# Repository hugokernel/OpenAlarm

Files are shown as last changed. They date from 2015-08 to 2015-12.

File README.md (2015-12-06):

OpenAlarm
=========

Un système d'alarme libre.

Caractéristiques :

- Uniquement basé sur des briques libres (OpenSource / OpenHardware)
- Autonomie très grande des modules capteurs, appelés « Node » (plusieurs mois)
- Les Node sont basés sur un µcontrolleur Atmel AVR ATMega32U4 et l'interface radio, sur un RFM12B (basé sur un Si4421 http://www.silabs.com/products/wireless/EZRadio/Pages/Si442021.aspx)
- Programmation et recharge simple des Node par USB (port µUSB inclu)
- Pas besoin de base : 2 Node suffisent à faire fonctionner une surveillance
- Possibilité de modifier les paramètres d'un Node à distance
- Technos utilisées : Arduino (Ino) pour les Node, et Python pour l'interface avec un PC
- Les entrées / sorties sont facilement accessible (au pas de 2.54mm)
- 2 leds (vertes et rouges) inclues sur chaque Node

Les premiers Node sont fonctionnel en version 1.5.0, les schémas de principe et PCB sont disponible en PDF dans le dossier https://github.com/hugokernel/OpenAlarm/blob/master/hardware/export/pdf/node/1.5.0/

Pour rester informer, ça se passe sur le site officiel d'OpenAlarm http://openalarm.net/, vous pouvez venir en parler sur le canal irc #madeinfr sur le réseau freenode.

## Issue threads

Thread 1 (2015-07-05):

Schémas et typons PDF

nicolasc-eu, 2015-07-05:
Hello,

Petite suggestion : un export PDF et/ou bitmap des schémas et typons serait bien appréciable, pour pouvoir notamment les consulter sur mobile.

À plus tard,

hugokernel, 2015-12-05:
Done ! https://github.com/hugokernel/OpenAlarm/tree/master/hardware/export/pdf/node/1.5.0

Closed 2015-12-05.

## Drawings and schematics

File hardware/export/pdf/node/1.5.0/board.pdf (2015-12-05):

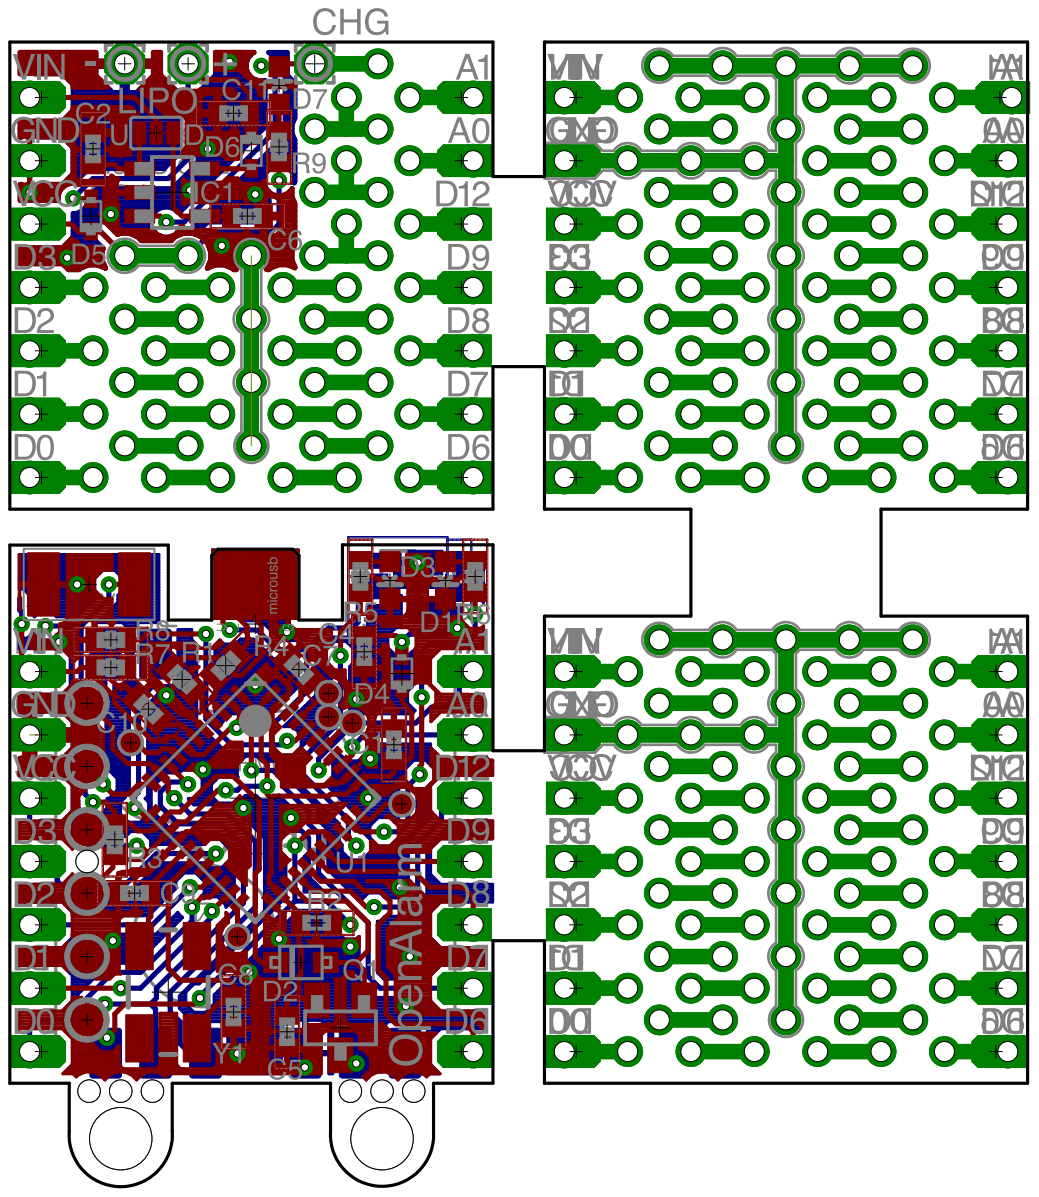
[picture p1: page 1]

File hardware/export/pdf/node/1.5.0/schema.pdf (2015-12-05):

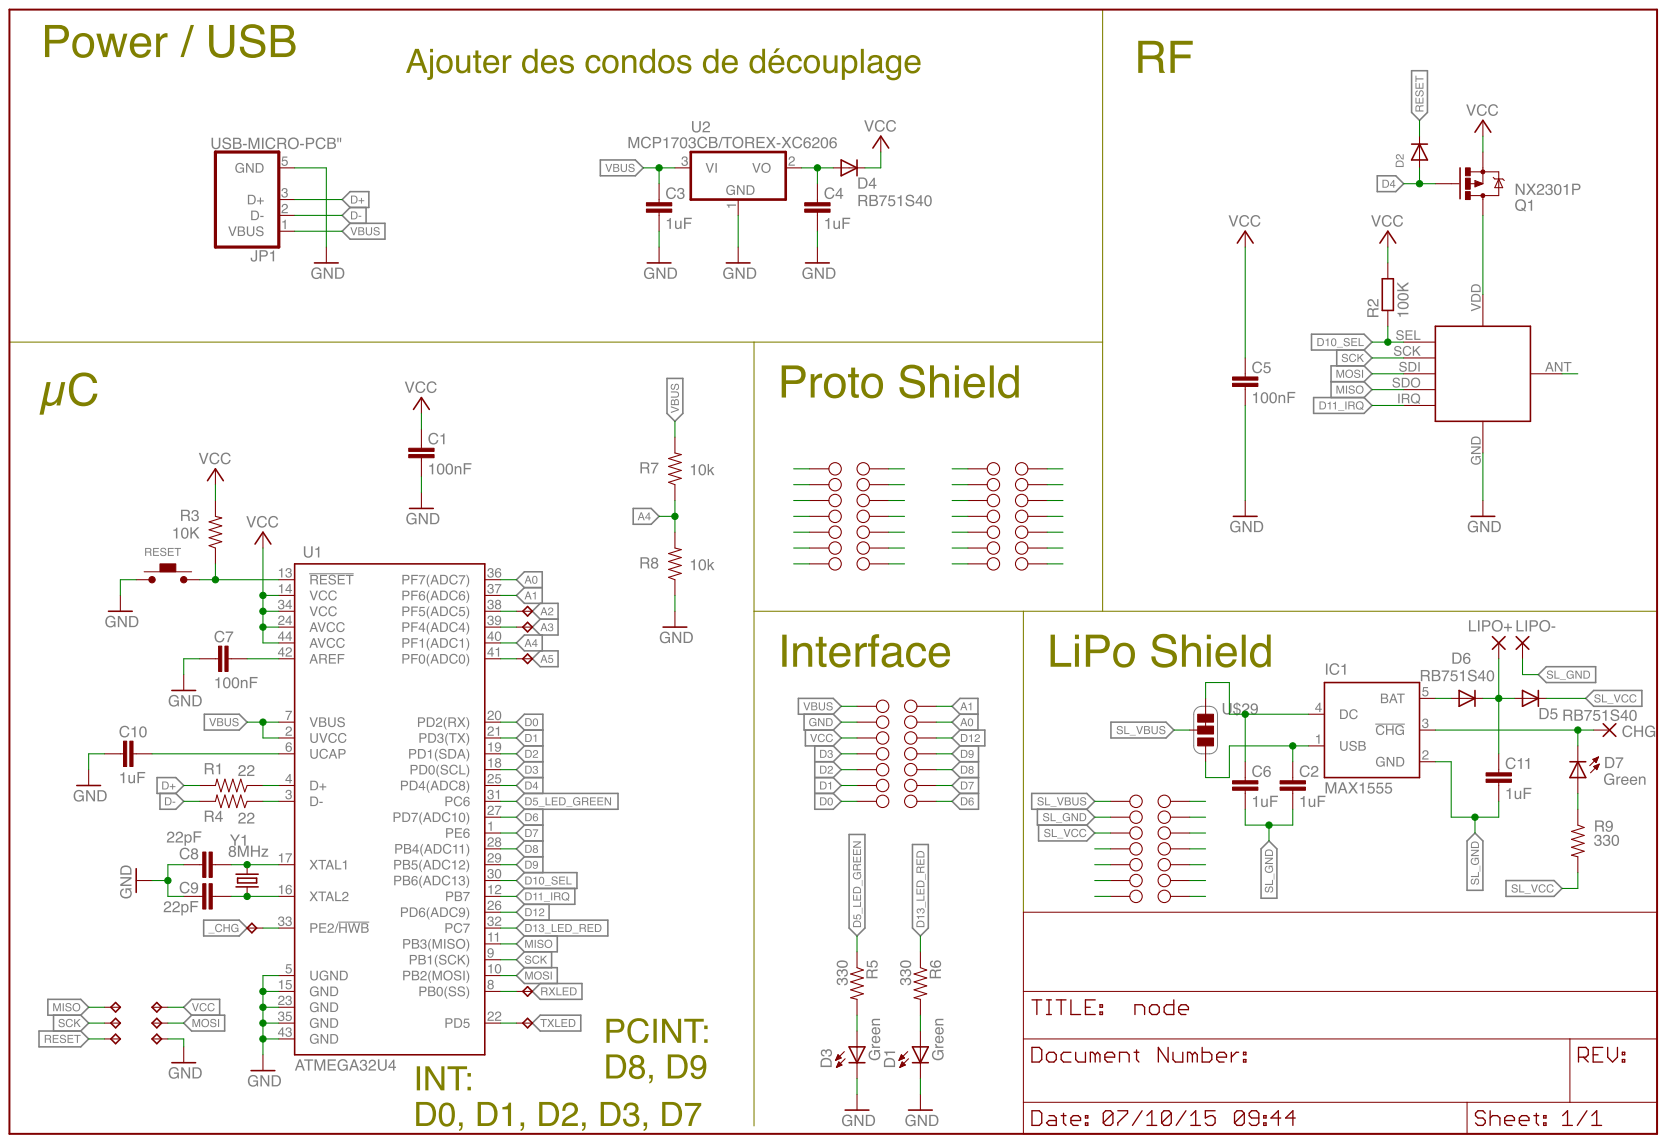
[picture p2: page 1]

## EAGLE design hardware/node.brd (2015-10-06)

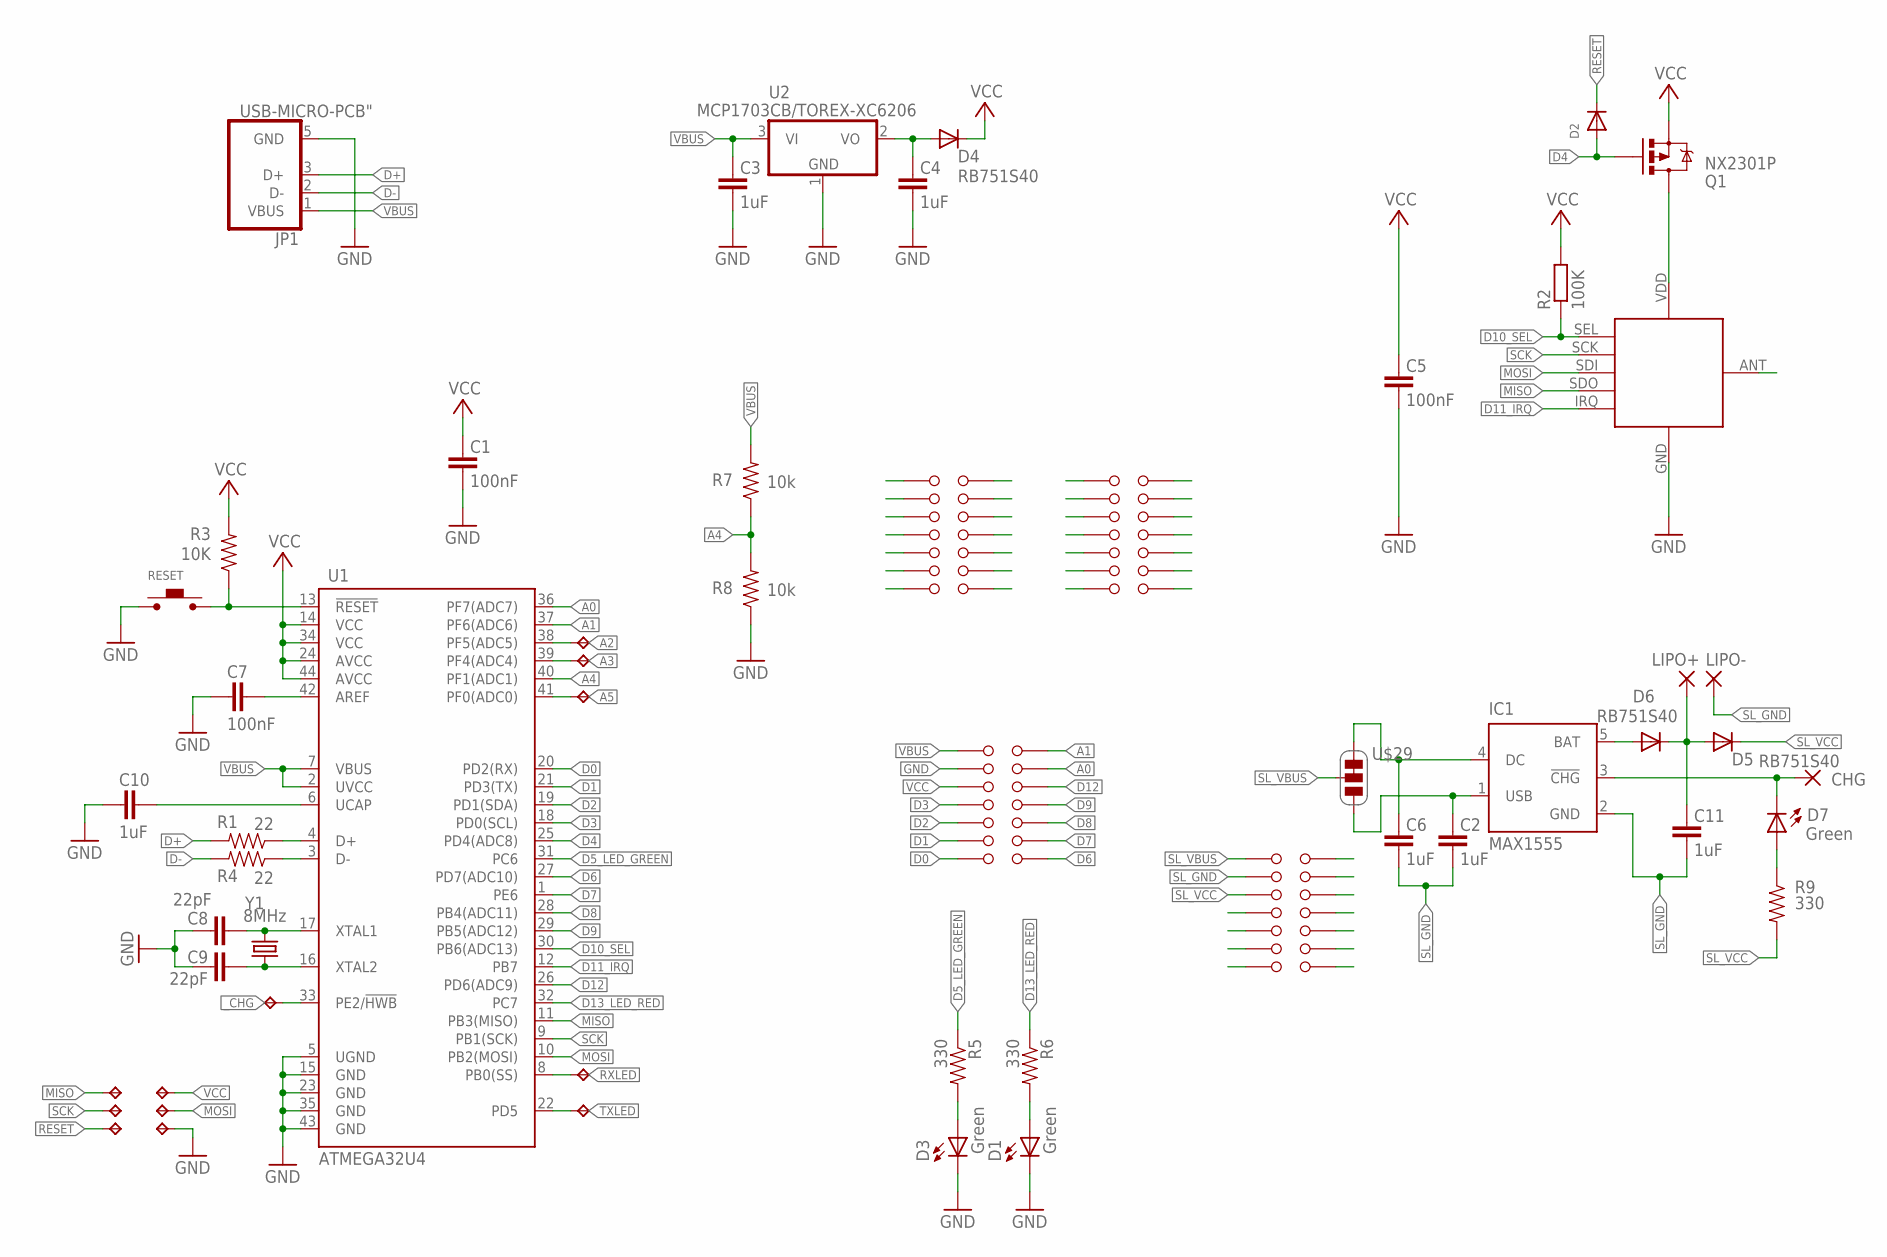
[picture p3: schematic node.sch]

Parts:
C1, C5, C7: 100nF; 0402-CAP
C2, C3, C4, C6, C10, C11: 1uF; 0402-CAP
C8, C9: 22pF; 0402-CAP
CHG: WIREPAD1,6/0,8; 1,6/0,8
D1, D3, D7: Green; LED-0603
D2: DIODESOD-323F; SOD-323F
D4, D5, D6: RB751S40; SOD523
IC1: MAX1555; SOT23-5L
JP1: USB-MICRO-PCB"; USB-MICRO-PCB
LIPO+: WIREPAD1,6/0,8; 1,6/0,8
LIPO-: WIREPAD1,6/0,8; 1,6/0,8
Q1: NX2301P; SOT23
R1, R4: 22; 0402-RES
R2: 100K; R0402
R3: 10K; 0402-RES
R5, R6, R9: 330; 0402-RES
R7, R8: 10k; 0402-RES
RESET: MICROSWITCH
RFMXX: RFM12B_MINPADS; RFM12B-MINPADS
TP1, TP2, TP3, TP4, TP5, TP14: TPTP13R; TP13R
TP7, TP8, TP9, TP10, TP11, TP12: TPTP08R; TP08R
U1: ATMEGA32U4; QFN-44-NOPAD
U2: MCP1703CB/TOREX-XC6206; SOT23
U$1, U$2, U$3, U$4, U$5, U$6, U$7, U$8, U$9, U$10, U$11, U$12, U$13, U$14, U$15, U$16, U$17, U$18, U$19, U$20, U$21, U$22, U$23, U$24, U$25, U$26, U$27, U$28, U$30, U$31, U$32, U$33, U$34, U$35, U$36, U$37, U$38, U$39, U$40, U$41, U$42, U$43, U$44, U$45, U$46, U$47, U$48, U$49, U$50, U$51, U$52, U$53, U$54, U$55, U$56, U$57: IOPAD
U$29: UJUMPER-SHORT
Y1: 8MHz; CRYSTAL-SMD-5X3

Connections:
A0: U1.36 (PF7(ADC7)), U$9.P$1
A1: U1.37 (PF6(ADC6)), U$8.P$1
A2: TP7.TP, U1.38 (PF5(ADC5))
A3: TP8.TP, U1.39 (PF4(ADC4))
A4: R7.1, R8.2, U1.40 (PF1(ADC1))
A5: TP10.TP, U1.41 (PF0(ADC0))
AREF: C7.2, U1.42 (AREF)
D0: U1.20 (PD2(RX)), U$2.P$1
D1: U1.21 (PD3(TX)), U$1.P$1
D2: U1.19 (PD1(SDA)), U$3.P$1
D3: U1.18 (PD0(SCL)), U$4.P$1
D4: D2.A, Q1.1 (G), U1.25 (PD4(ADC8))
D5_LED_GREEN: R5.1, U1.31 (PC6)
D6: U1.27 (PD7(ADC10)), U$14.P$1
D7: U1.1 (PE6), U$13.P$1
D8: U1.28 (PB4(ADC11)), U$12.P$1
D9: U1.29 (PB5(ADC12)), U$11.P$1
D10_SEL: R2.1, RFMXX.SEL, U1.30 (PB6(ADC13))
D11_IRQ: RFMXX.IRQ, U1.12 (PB7)
D12: U1.26 (PD6(ADC9)), U$10.P$1
D13_LED_RED: R6.1, U1.32 (PC7)
D+: JP1.3 (D+), R1.2
D-: JP1.2 (D-), R4.2
GND: C1.1, C3.1, C4.1, C5.1, C7.1, C8.2, C9.2, C10.1, D1.C, D3.C, JP1.5 (GND), R8.1, RESET.P$1, RFMXX.GND, TP5.TP, U1.5 (UGND), U1.15 (GND), U1.23 (GND), U1.35 (GND), U1.43 (GND), U2.1 (GND), U$6.P$1
MISO: RFMXX.SDO (SDO/MISO), TP14.TP, U1.11 (PB3(MISO))
MOSI: RFMXX.SDI (SDI/MOSI), TP4.TP, U1.10 (PB2(MOSI))
unnamed: C9.1, U1.16 (XTAL2), Y1.1
unnamed: R1.1, U1.4 (D+)
unnamed: C8.1, U1.17 (XTAL1), Y1.3 (2)
unnamed: C10.2, U1.6 (UCAP)
unnamed: D1.A, R6.2
unnamed: R4.1, U1.3 (D-)
unnamed: D3.A, R5.2
unnamed: Q1.3 (D), RFMXX.VDD
unnamed: D7.A, R9.1
unnamed: CHG.1, D7.C, IC1.3 (!CHG)
unnamed: C6.2, IC1.4 (DC), U$29.C0
unnamed: C2.2, IC1.1 (USB), U$29.C1
unnamed: D6.A, IC1.5 (BAT)
unnamed: C11.2, D5.A, D6.C, LIPO+.1
RESET: D2.C, R3.1, RESET.P$2, TP3.TP, U1.13 (!RESET)
RXLED: TP11.TP, U1.8 (PB0(SS))
SCK: RFMXX.SCK, TP2.TP, U1.9 (PB1(SCK))
SL_GND: C2.1, C6.1, C11.1, IC1.2 (GND), LIPO-.1, U$31.P$1
SL_VBUS: U$29.COM, U$30.P$1
SL_VCC: D5.C, R9.2, U$32.P$1
TXLED: TP9.TP, U1.22 (PD5)
VBAT: C4.2, D4.A, U2.2 (VO)
VBUS: C3.2, JP1.1 (VBUS), R7.2, U1.2 (UVCC), U1.7 (VBUS), U2.3 (VI), U$7.P$1
VCC: C1.2, C5.2, D4.C, Q1.2 (S), R2.2, R3.2, TP1.TP, U1.14 (VCC), U1.24 (AVCC), U1.34 (VCC), U1.44 (AVCC), U$5.P$1
_CHG: TP12.TP, U1.33 (PE2/!HWB)

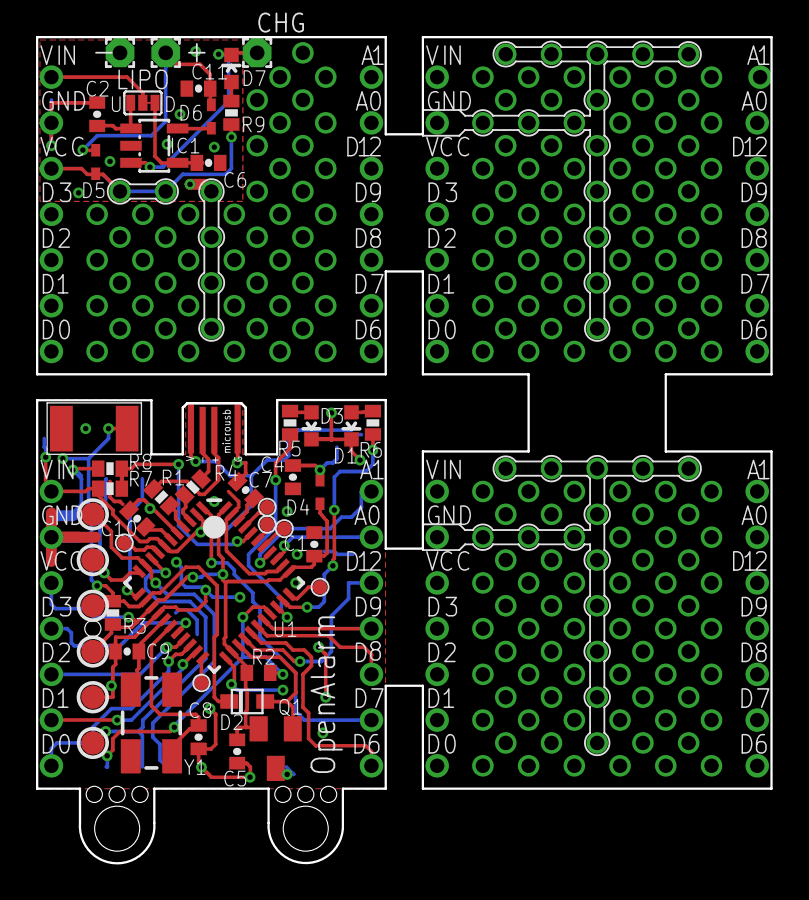
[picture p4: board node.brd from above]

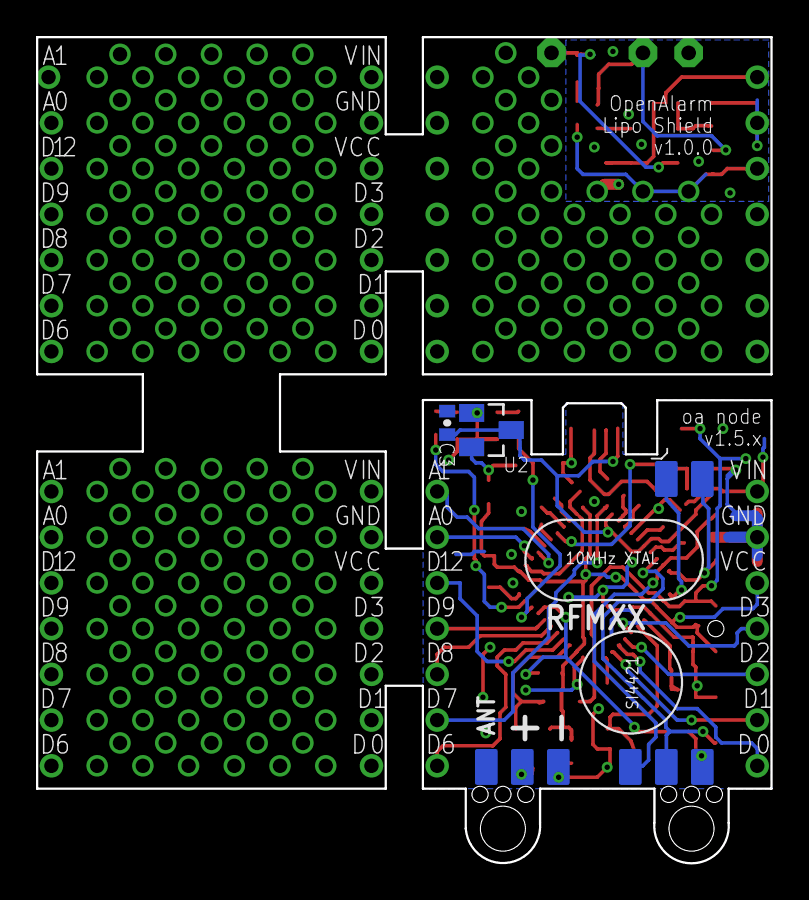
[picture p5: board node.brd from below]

Board: 2 copper layers, 40.8 x 45.9 mm, 107 parts (3 on the bottom side), 51 nets.

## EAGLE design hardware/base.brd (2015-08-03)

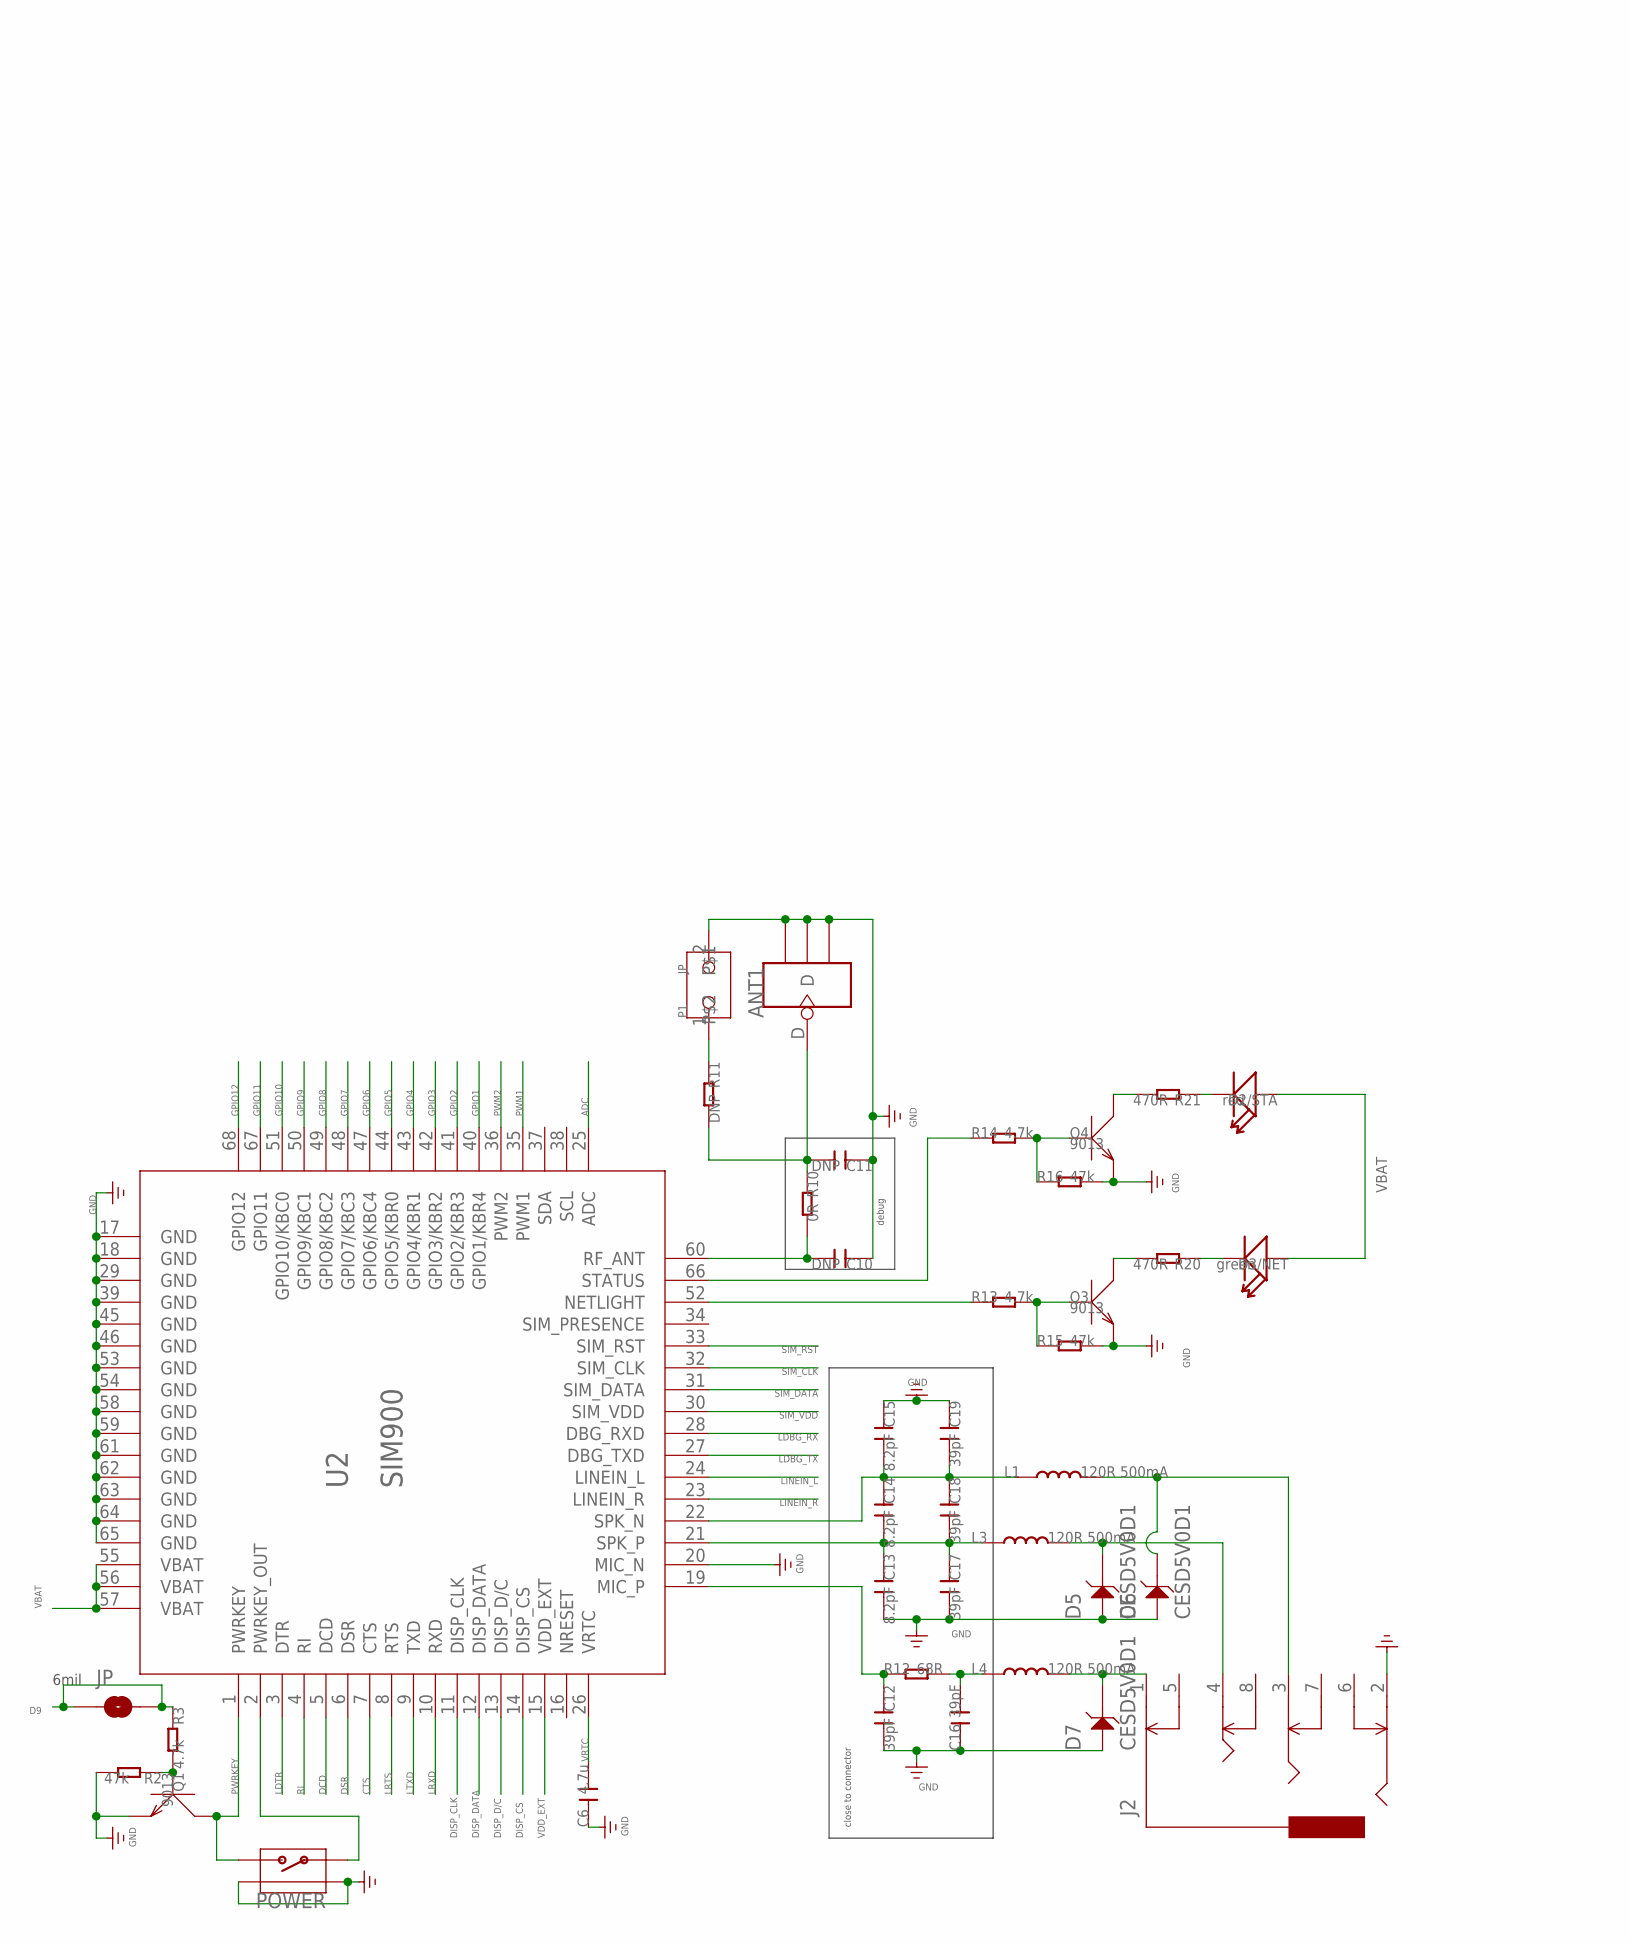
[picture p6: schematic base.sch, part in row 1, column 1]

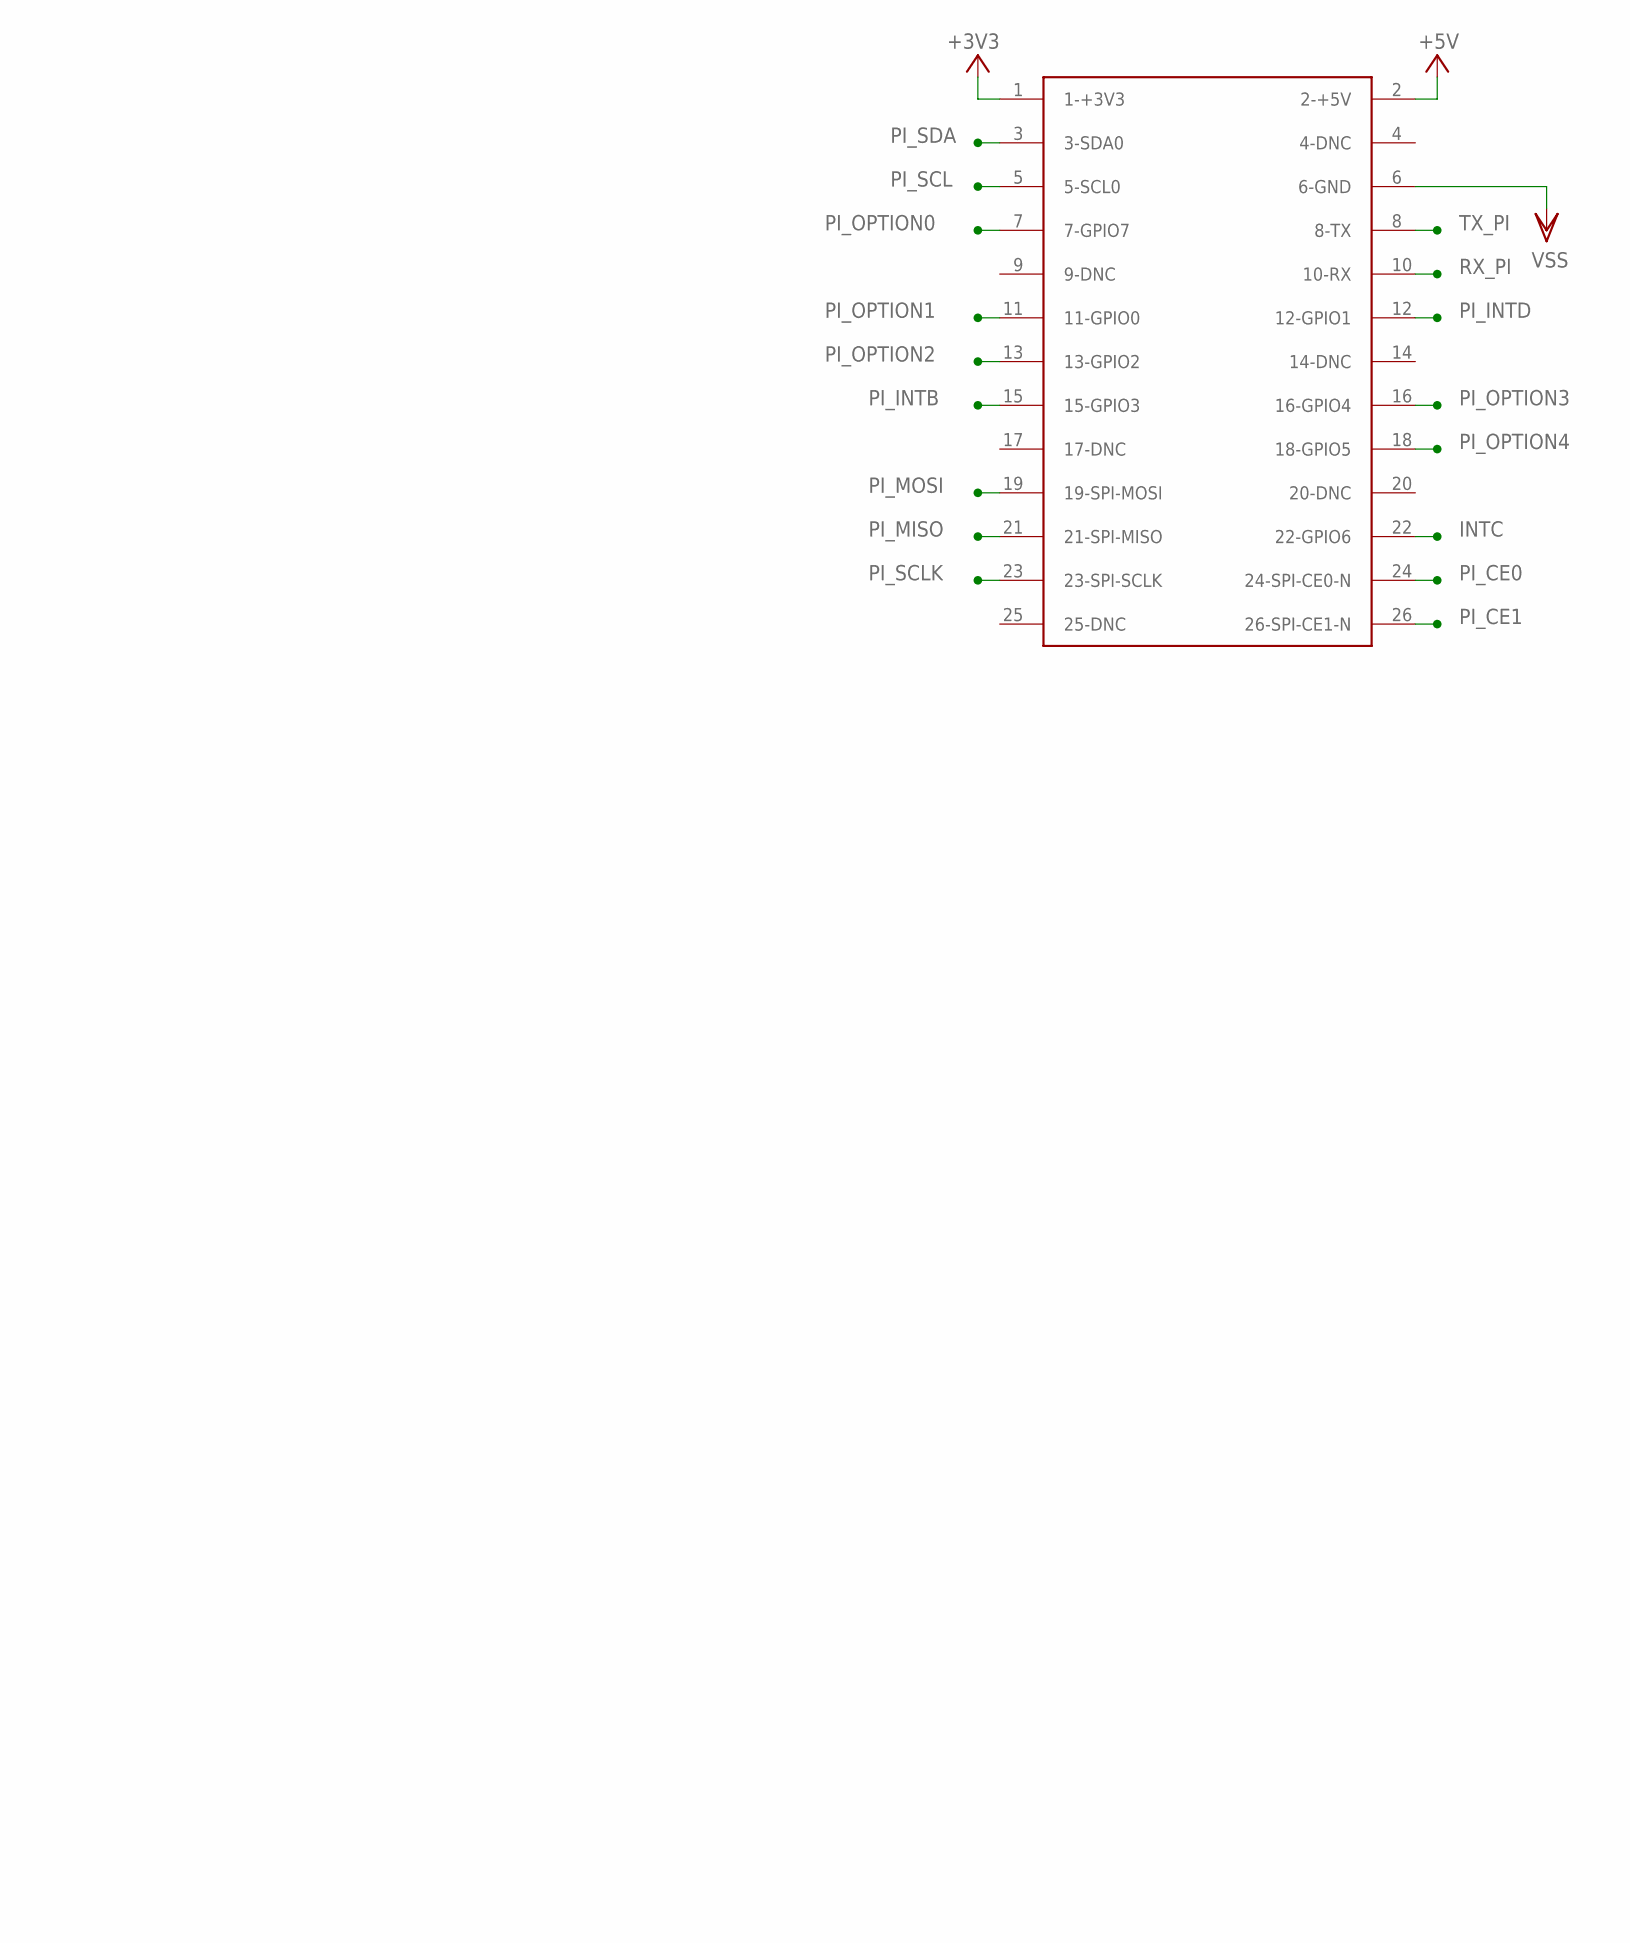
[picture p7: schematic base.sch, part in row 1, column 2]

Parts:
ANT1: ANTENNA-U-FL; 4P-U-FL
C6: 4.7u; C0805
C10, C11: DNP; C0603
C12, C16, C17, C18, C19: 39pF; C0603
C13, C14, C15: 8.2pF; C0603
D2/STA: red; LED-0603
D3/NET: green; LED-0603
D5, D6, D7: CESD5V0D1; SOD123-2.7X1.6
J2: AUDIO-8P'PJ-3536-L6S'; 8P-3.5-SMD
JP: PAD-SOLDERJUMPERNC; 2P-SMD-3.3X2
L1, L3, L4: 120R 500mA; L0603
P1: JP
POWER: BUTTON-4P-REINFORCE'TS-118E'; 4P-SMD-7X3.5X3.5H
Q1, Q3, Q4: 9013; SOT23
R2, R15, R16: 47k; R0603
R3, R13, R14: 4.7k; R0603
R10: 0R; R0603
R11: DNP; R0603
R12: 68R; R0603
R20, R21: 470R; R0603
U2: SIM900
U$3: RASPBERRY-PILIGHT-HOLE; RASPBERRY-PI-LIGHT-HOLE

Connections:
+3V3: U$3.1 (1-+3V3)
+5V: U$3.2 (2-+5V)
ADC: U2.25 (ADC)
CTS: U2.7 (CTS)
D9: JP.1, JP.2, R3.1
DCD: U2.5 (DCD)
DISP_CLK: U2.11 (DISP_CLK)
DISP_CS: U2.14 (DISP_CS)
DISP_D/C: U2.13 (DISP_D/C)
DISP_DATA: U2.12 (DISP_DATA)
DSR: U2.6 (DSR)
GND: ANT1.GND1, ANT1.GND2, ANT1.GND3, C6.1, C10.1, C11.1, C12.2, C13.2, C15.1, C16.1, C17.2, C19.1, D5.1, D6.1, D7.1, J2.2, P1.2, POWER.S1, POWER.S2, Q1.2 (E), Q3.2 (E), Q4.2 (E), R2.2, R15.2, R16.2, U2.17 (GND), U2.18 (GND), U2.20 (MIC_N), U2.29 (GND), U2.39 (GND), U2.45 (GND), U2.46 (GND), U2.53 (GND), U2.54 (GND), U2.58 (GND), U2.59 (GND), U2.61 (GND), U2.62 (GND), U2.63 (GND), U2.64 (GND), U2.65 (GND)
GPIO1: U2.40 (GPIO1/KBR4)
GPIO2: U2.41 (GPIO2/KBR3)
GPIO3: U2.42 (GPIO3/KBR2)
GPIO4: U2.43 (GPIO4/KBR1)
GPIO5: U2.44 (GPIO5/KBR0)
GPIO6: U2.47 (GPIO6/KBC4)
GPIO7: U2.48 (GPIO7/KBC3)
GPIO8: U2.49 (GPIO8/KBC2)
GPIO9: U2.50 (GPIO9/KBC1)
GPIO10: U2.51 (GPIO10/KBC0)
GPIO11: U2.67 (GPIO11)
GPIO12: U2.68 (GPIO12)
INTC: U$3.22 (22-GPIO6)
LDBG_RX: U2.28 (DBG_RXD)
LDBG_TX: U2.27 (DBG_TXD)
LDTR: U2.3 (DTR)
LINEIN_L: U2.24 (LINEIN_L)
LINEIN_R: U2.23 (LINEIN_R)
LRTS: U2.8 (RTS)
LRXD: U2.10 (RXD)
LTXD: U2.9 (TXD)
unnamed: D2/STA.-, R21.1
unnamed: C10.2, R10.2, U2.60 (RF_ANT)
unnamed: Q3.3 (C), R20.2
unnamed: D3/NET.-, R20.1
unnamed: Q3.1 (B), R13.2, R15.1
unnamed: R13.1, U2.52 (NETLIGHT)
unnamed: POWER.1, U2.2 (PWRKEY_OUT)
unnamed: C12.1, R12.1, U2.19 (MIC_P)
unnamed: C13.1, C14.2, C17.1, C18.2, L3.1, U2.21 (SPK_P)
unnamed: Q4.3 (C), R21.2
unnamed: Q4.1 (B), R14.2, R16.1
unnamed: C14.1, C15.2, C18.1, C19.2, L1.1, U2.22 (SPK_N)
unnamed: R14.1, U2.66 (STATUS)
unnamed: ANT1.D, C11.2, R10.1, R11.2
unnamed: C16.2, L4.1, R12.2
unnamed: Q1.1 (B), R2.1, R3.2
unnamed: D7.2, J2.1, L4.2
unnamed: D5.2, J2.4, L3.2
unnamed: D6.2, J2.3, L1.2
unnamed: P1.1, R11.1
PI_CE0: U$3.24 (24-SPI-CE0-N)
PI_CE1: U$3.26 (26-SPI-CE1-N)
PI_INTB: U$3.15 (15-GPIO3)
PI_INTD: U$3.12 (12-GPIO1)
PI_MISO: U$3.21 (21-SPI-MISO)
PI_MOSI: U$3.19 (19-SPI-MOSI)
PI_OPTION0: U$3.7 (7-GPIO7)
PI_OPTION1: U$3.11 (11-GPIO0)
PI_OPTION2: U$3.13 (13-GPIO2)
PI_OPTION3: U$3.16 (16-GPIO4)
PI_OPTION4: U$3.18 (18-GPIO5)
PI_SCL: U$3.5 (5-SCL0)
PI_SCLK: U$3.23 (23-SPI-SCLK)
PI_SDA: U$3.3 (3-SDA0)
PWM1: U2.35 (PWM1)
PWM2: U2.36 (PWM2)
PWRKEY: POWER.2, Q1.3 (C), U2.1 (PWRKEY)
RI: U2.4 (RI)
RX_PI: U$3.10 (10-RX)
SIM_CLK: U2.32 (SIM_CLK)
SIM_DATA: U2.31 (SIM_DATA)
SIM_RST: U2.33 (SIM_RST)
SIM_VDD: U2.30 (SIM_VDD)
TX_PI: U$3.8 (8-TX)
VBAT: D2/STA.+, D3/NET.+, U2.55 (VBAT), U2.56 (VBAT), U2.57 (VBAT)
VDD_EXT: U2.15 (VDD_EXT)
VRTC: C6.2, U2.26 (VRTC)
VSS: U$3.6 (6-GND)

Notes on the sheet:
close to connector
debug
6mil

Board: 2 copper layers, 42 parts (1 on the bottom side), 25 nets, no tracks yet.

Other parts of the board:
U$2: OSHW_8X350_NOTEXT
U$5: OSHW_6X150_NOTEXT

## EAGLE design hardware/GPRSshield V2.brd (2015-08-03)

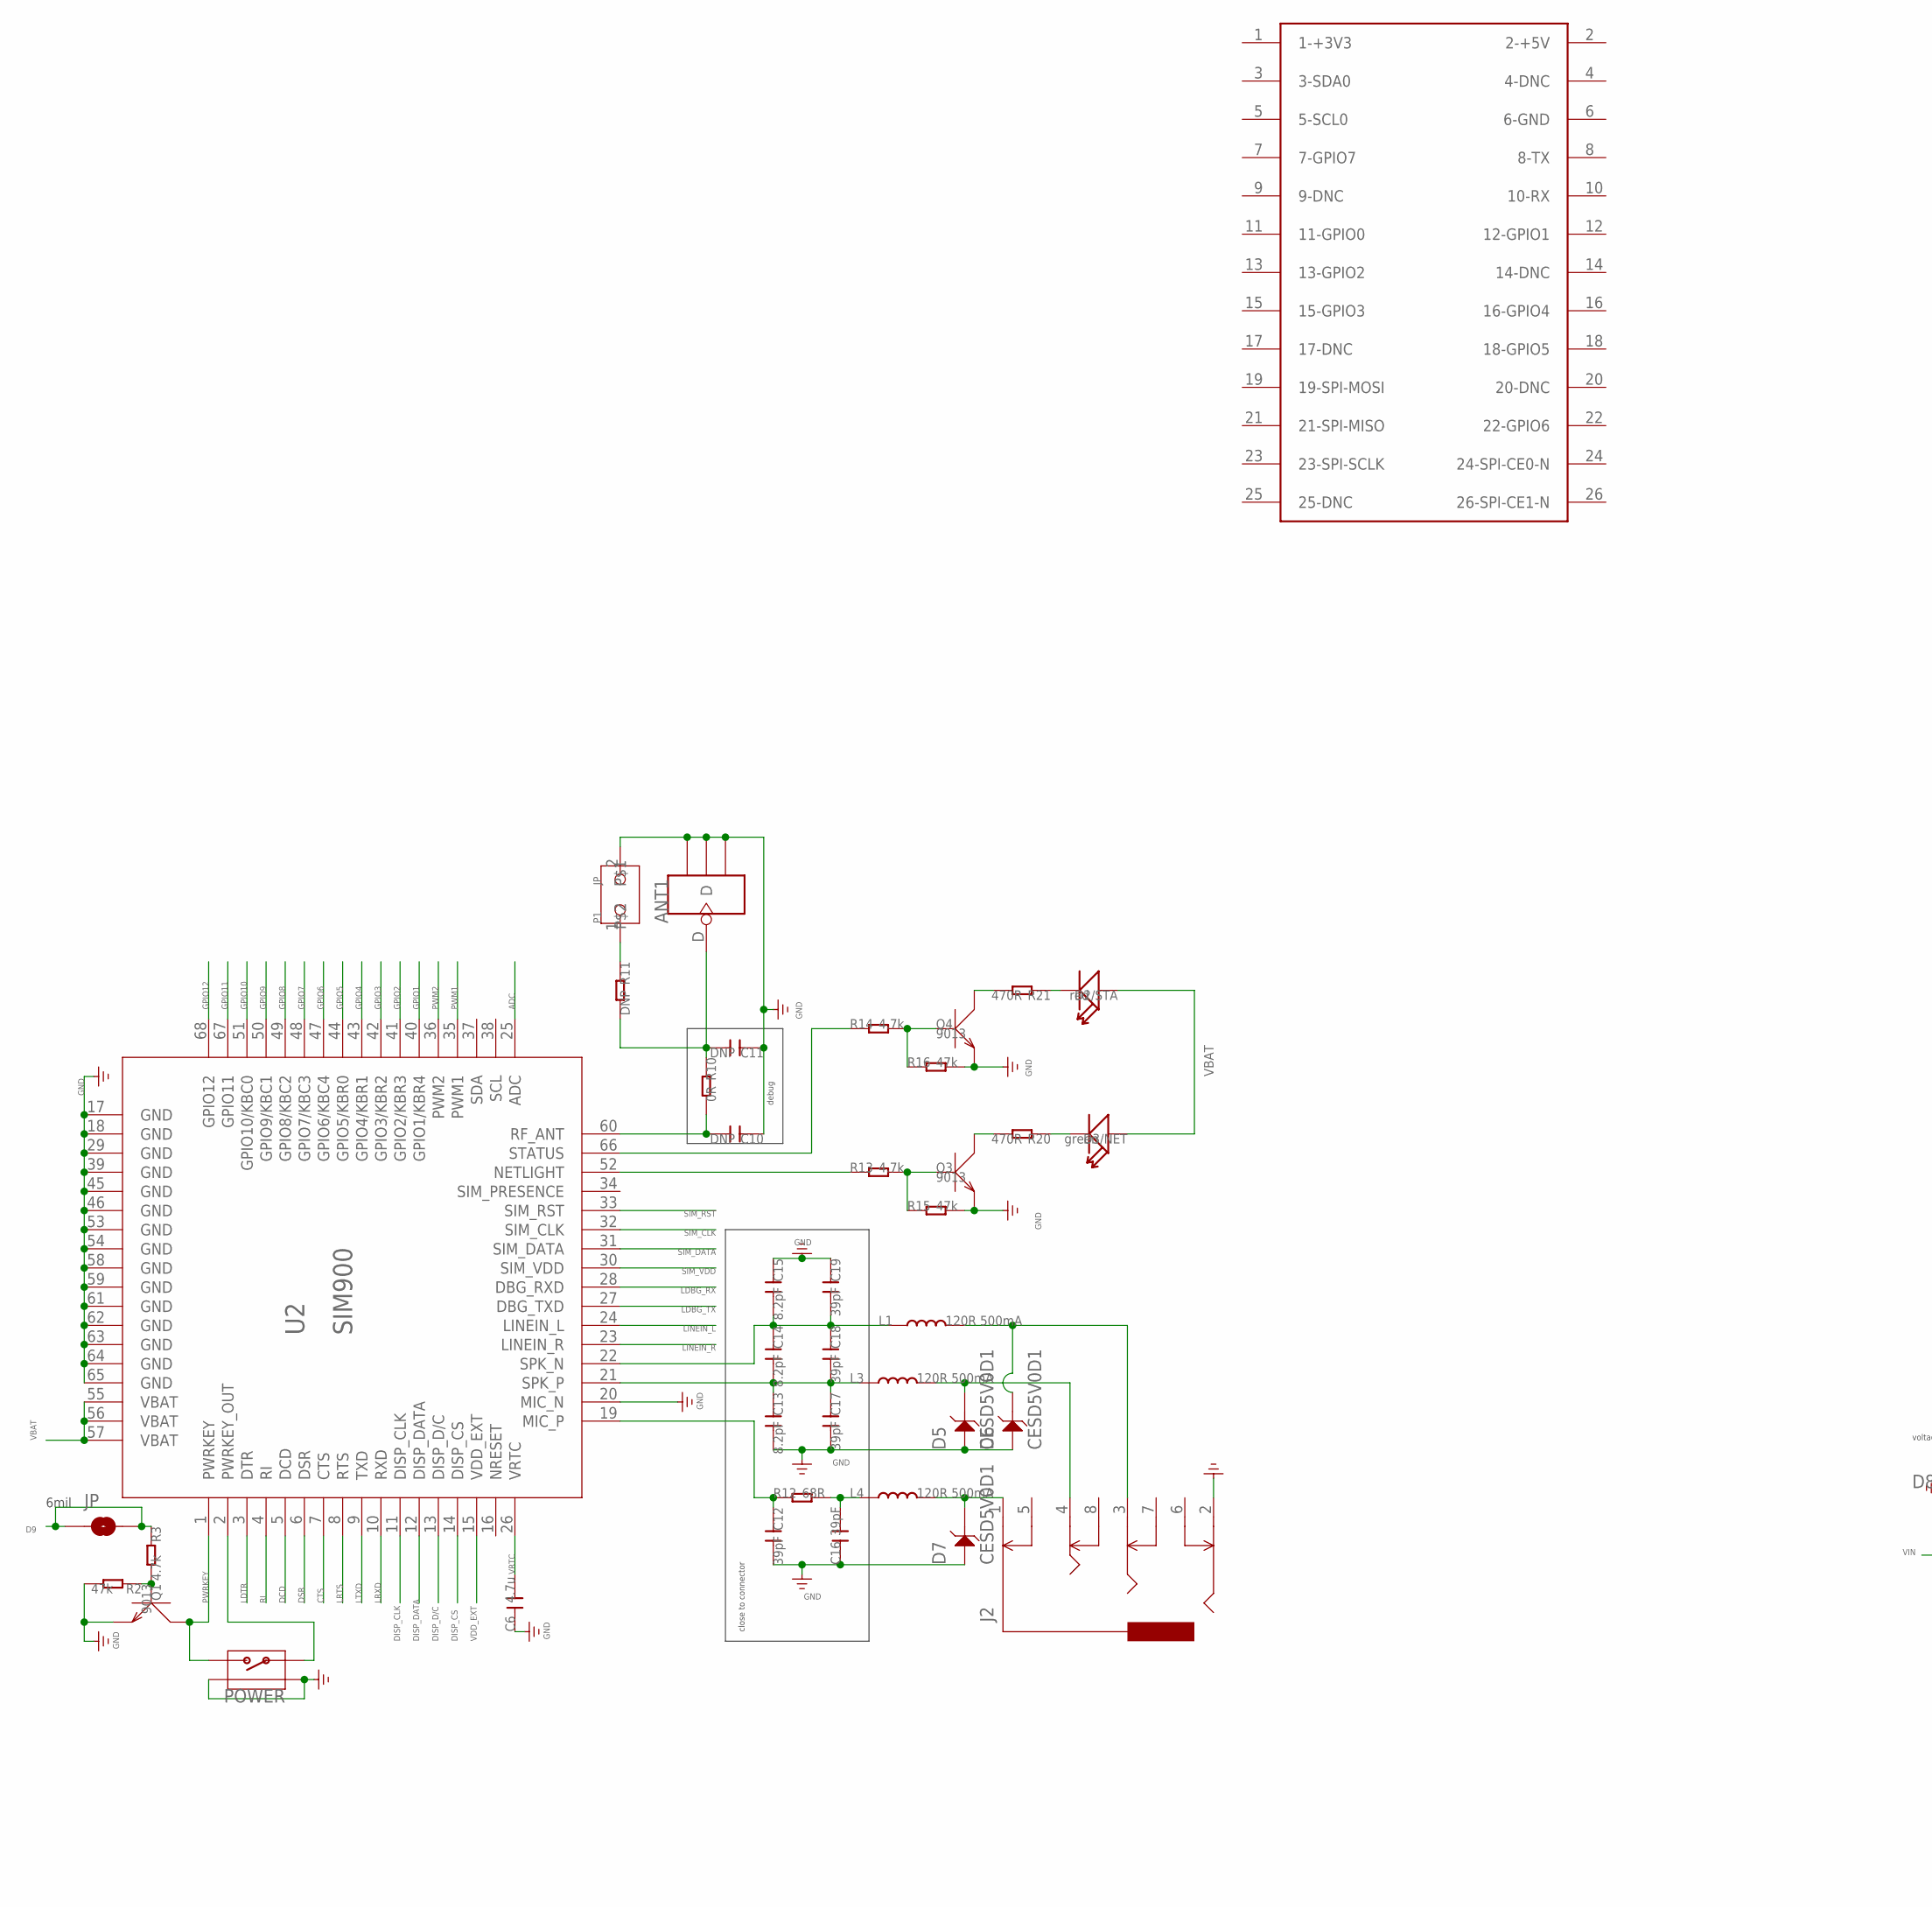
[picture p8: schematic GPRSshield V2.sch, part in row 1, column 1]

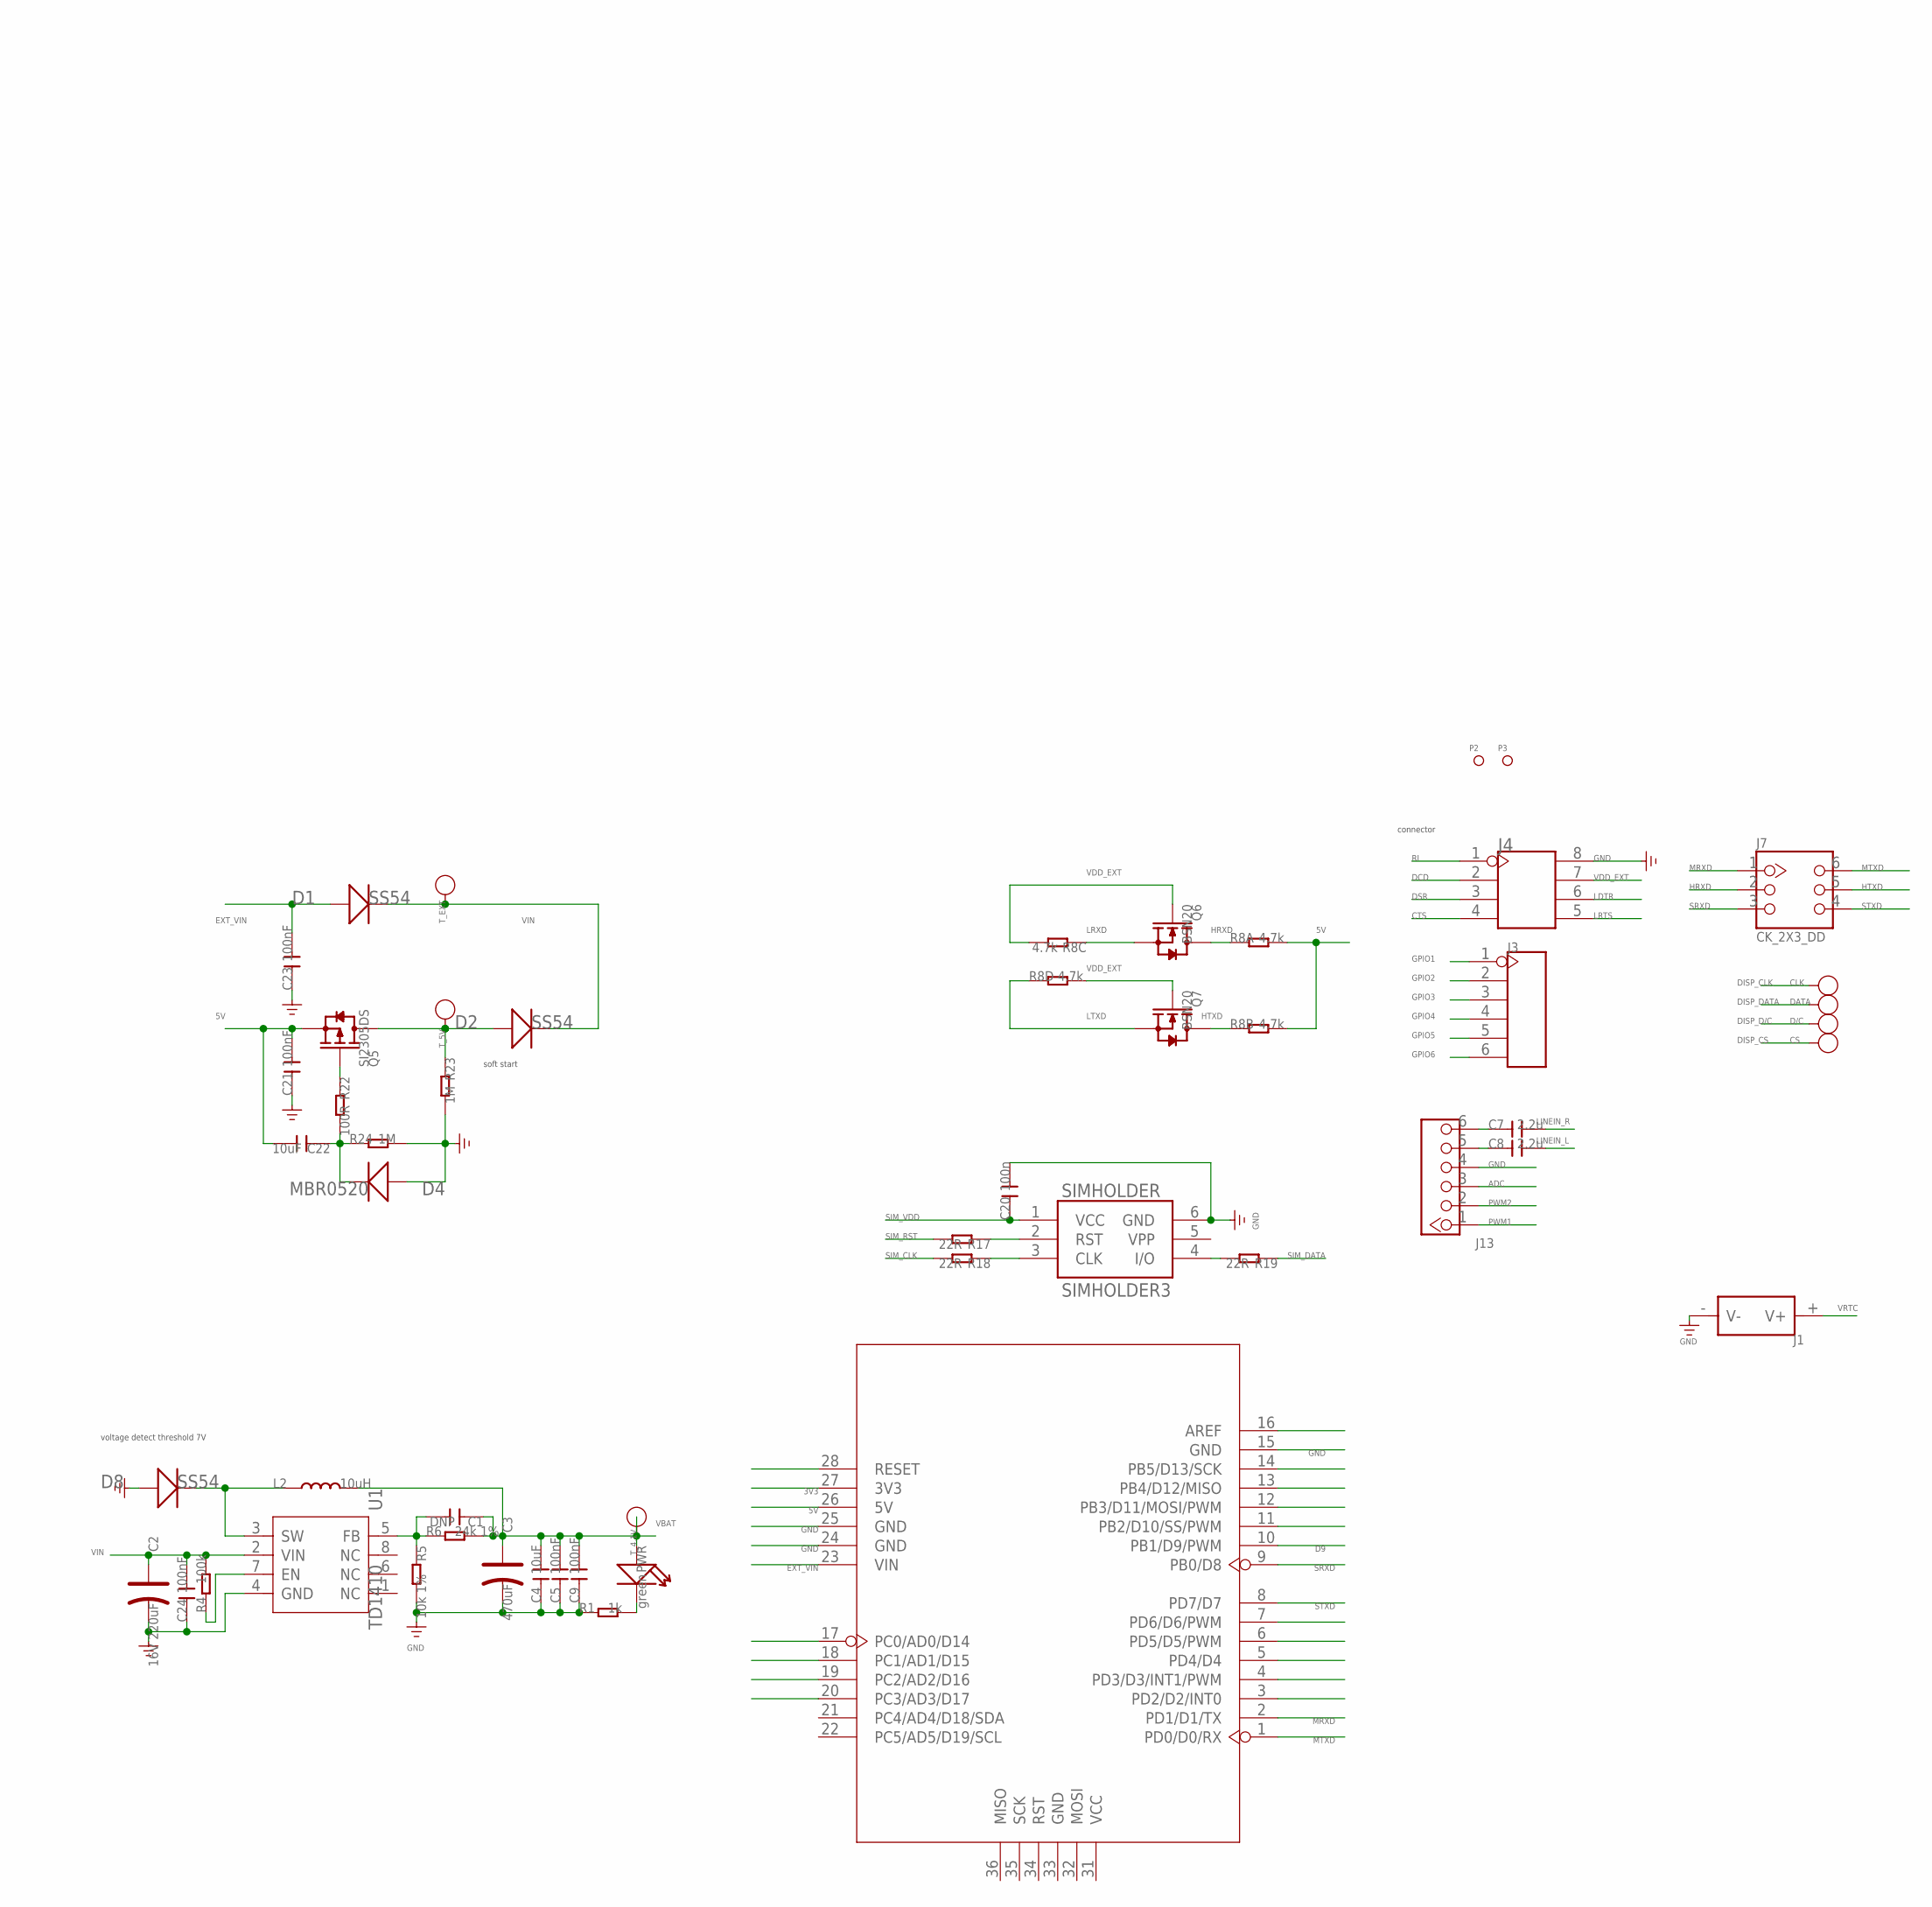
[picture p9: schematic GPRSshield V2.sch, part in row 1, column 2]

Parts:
ANT1: ANTENNA-U-FL; 4P-U-FL
C1, C10, C11: DNP; C0603
C2: 16V 220uF; ELECTRO-SMD-D-5.6MM
C3: 470uF; AVX-D
C4, C22: 10uF; C0805
C5, C9, C21, C23, C24: 100nF; C0603
C6: 4.7u; C0805
C7, C8: 2.2u; C0805
C12, C16, C17, C18, C19: 39pF; C0603
C13, C14, C15: 8.2pF; C0603
C20: 100n; C0603
CLK: PAD-TEST-POINT-CIRCLE'4545'; TP_4545
CS: PAD-TEST-POINT-CIRCLE'4545'; TP_4545
D1, D2, D8: SS54; SMB
D2/STA: red; LED-0603
D3/NET: green; LED-0603
D4: MBR0520; SOD123-2.7X1.6
D5, D6, D7: CESD5V0D1; SOD123-2.7X1.6
D/C: PAD-TEST-POINT-CIRCLE'4545'; TP_4545
DATA: PAD-TEST-POINT-CIRCLE'4545'; TP_4545
J1: HOLDER-BAT; SMD-CR1220-2
J2: AUDIO-8P'PJ-3536-L6S'; 8P-3.5-SMD
J3: HEADER-6P-65/35MIL; 6P-2.54-65/35MIL
J4: HEADER-2X4P-2.54; 2X4P-2.54
J7: CK_2X3_DD; CK_2X3
J13: HEADER_1X6; CK_1X6
JP: PAD-SOLDERJUMPERNC; 2P-SMD-3.3X2
L1, L3, L4: 120R 500mA; L0603
L2: 10uH; L0630
P1: JP
P2, P3: PAD-MARK; ROUND-MARK-1.0
POWER: BUTTON-4P-REINFORCE'TS-118E'; 4P-SMD-7X3.5X3.5H
PWR: green; D0603
Q1, Q3, Q4: 9013; SOT23
Q5: SI2305DS; SOT23
Q6, Q7: BSN20; SOT23
R1: 1k; R0603
R2, R15, R16: 47k; R0603
R3, R13, R14: 4.7k; R0603
R4: 100k; R0603
R5: 10k 1%; R0603
R6: 24k 1%; R0603
R8: 4.7k; 1206-8-3.3X2.4
R10: 0R; R0603
R11: DNP; R0603
R12: 68R; R0603
R17, R18, R19: 22R; R0603
R20, R21: 470R; R0603
R22: 100R; R0603
R23, R24: 1M; R0603
SIMHOLDER: SIMHOLDER3
T_4.1V, T_5V: PAD-TEST-POINT-CIRCLE'4545'; TP_4545; PARTNO DNP
T_EXT: PAD-TEST-POINT-CIRCLE'4545'; TP_4545; PARTNO DNP
U1: TD1410; SOP8
U2: SIM900
U3: ARDUINO'W/O-SILK'; ARDUINO-W/O-SILK
U$4: RASPBERRY-PI

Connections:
3V3: U3.27 (3V3)
5V: C21.2, C22.2, Q5.2 (S), R8.7 (2), R8.8 (2), U3.26 (5V)
ADC: J13.3, U2.25 (ADC)
CTS: J4.4, U2.7 (CTS)
D9: JP.1, JP.2, R3.1, U3.10 (PB1/D9/PWM)
DCD: J4.2, U2.5 (DCD)
DISP_CLK: CLK.T, U2.11 (DISP_CLK)
DISP_CS: CS.T, U2.14 (DISP_CS)
DISP_D/C: D/C.T, U2.13 (DISP_D/C)
DISP_DATA: DATA.T, U2.12 (DISP_DATA)
DSR: J4.3, U2.6 (DSR)
EXT_VIN: C23.2, D1.+, U3.23 (VIN)
GND: ANT1.GND1, ANT1.GND2, ANT1.GND3, C2.-, C3.-, C4.1, C5.1, C6.1, C9.1, C10.1, C11.1, C12.2, C13.2, C15.1, C16.1, C17.2, C19.1, C20.2, C21.1, C23.1, C24.1, D4.1 (+), D5.1, D6.1, D7.1, D8.+, J1.- (V-), J2.2, J4.8, J13.4, P1.2, POWER.S1, POWER.S2, Q1.2 (E), Q3.2 (E), Q4.2 (E), R1.1, R2.2, R5.2, R15.2, R16.2, R23.2, R24.2, SIMHOLDER.6 (GND), U1.4 (GND), U2.17 (GND), U2.18 (GND), U2.20 (MIC_N), U2.29 (GND), U2.39 (GND), U2.45 (GND), U2.46 (GND), U2.53 (GND), U2.54 (GND), U2.58 (GND), U2.59 (GND), U2.61 (GND), U2.62 (GND), U2.63 (GND), U2.64 (GND), U2.65 (GND), U3.15 (GND), U3.24 (GND), U3.25 (GND)
GPIO1: J3.1, U2.40 (GPIO1/KBR4)
GPIO2: J3.2, U2.41 (GPIO2/KBR3)
GPIO3: J3.3, U2.42 (GPIO3/KBR2)
GPIO4: J3.4, U2.43 (GPIO4/KBR1)
GPIO5: J3.5, U2.44 (GPIO5/KBR0)
GPIO6: J3.6, U2.47 (GPIO6/KBC4)
GPIO7: U2.48 (GPIO7/KBC3)
GPIO8: U2.49 (GPIO8/KBC2)
GPIO9: U2.50 (GPIO9/KBC1)
GPIO10: U2.51 (GPIO10/KBC0)
GPIO11: U2.67 (GPIO11)
GPIO12: U2.68 (GPIO12)
HRXD: J7.2, Q6.3 (D), R8.1
HTXD: J7.5, Q7.3 (D), R8.2 (1)
LDBG_RX: U2.28 (DBG_RXD)
LDBG_TX: U2.27 (DBG_TXD)
LDTR: J4.6, U2.3 (DTR)
LINEIN_L: C8.2, U2.24 (LINEIN_L)
LINEIN_R: C7.2, U2.23 (LINEIN_R)
LRTS: J4.5, U2.8 (RTS)
LRXD: Q6.2 (S), R8.3 (1), U2.10 (RXD)
LTXD: Q7.2 (S), R8.4 (1), U2.9 (TXD)
MRXD: J7.1, U3.2 (PD1/D1/TX)
MTXD: J7.6, U3.1 (PD0/D0/RX)
unnamed: C10.2, R10.2, U2.60 (RF_ANT)
unnamed: D2.+, Q5.3 (D), R23.1, T_5V.T
unnamed: Q3.3 (C), R20.2
unnamed: R19.2, SIMHOLDER.4 (I/O)
unnamed: R18.1, SIMHOLDER.3 (CLK)
unnamed: R17.1, SIMHOLDER.2 (RST)
unnamed: D3/NET.-, R20.1
unnamed: Q3.1 (B), R13.2, R15.1
unnamed: PWR.-, R1.2
unnamed: R13.1, U2.52 (NETLIGHT)
unnamed: POWER.1, U2.2 (PWRKEY_OUT)
unnamed: R4.1, U1.7 (EN)
unnamed: C12.1, R12.1, U2.19 (MIC_P)
unnamed: C13.1, C14.2, C17.1, C18.2, L3.1, U2.21 (SPK_P)
unnamed: Q4.3 (C), R21.2
unnamed: D2/STA.-, R21.1
unnamed: Q4.1 (B), R14.2, R16.1
unnamed: C14.1, C15.2, C18.1, C19.2, L1.1, U2.22 (SPK_N)
unnamed: R14.1, U2.66 (STATUS)
unnamed: ANT1.D, C11.2, R10.1, R11.2
unnamed: C7.1, J13.6
unnamed: C8.1, J13.5
unnamed: C16.2, L4.1, R12.2
unnamed: Q5.1 (G), R22.1
unnamed: Q1.1 (B), R2.1, R3.2
unnamed: D8.-, L2.1, U1.3 (SW)
unnamed: C22.1, D4.2 (-), R22.2, R24.1
unnamed: D7.2, J2.1, L4.2
unnamed: C1.2, R5.1, R6.1, U1.5 (FB)
unnamed: D5.2, J2.4, L3.2
unnamed: D6.2, J2.3, L1.2
unnamed: P1.1, R11.1
PWM1: J13.1, U2.35 (PWM1)
PWM2: J13.2, U2.36 (PWM2)
PWRKEY: POWER.2, Q1.3 (C), U2.1 (PWRKEY)
RI: J4.1, U2.4 (RI)
SIM_CLK: R18.2, U2.32 (SIM_CLK)
SIM_DATA: R19.1, U2.31 (SIM_DATA)
SIM_RST: R17.2, U2.33 (SIM_RST)
SIM_VDD: C20.1, SIMHOLDER.1 (VCC), U2.30 (SIM_VDD)
SRXD: J7.3, U3.9 (PB0/D8)
STXD: J7.4, U3.8 (PD7/D7)
VBAT: C1.1, C3.+, C4.2, C5.2, C9.2, D2/STA.+, D3/NET.+, L2.2, PWR.+, R6.2, T_4.1V.T, U2.55 (VBAT), U2.56 (VBAT), U2.57 (VBAT)
VDD_EXT: J4.7, Q6.1 (G), Q7.1 (G), R8.5 (2), R8.6 (2), U2.15 (VDD_EXT)
VIN: C2.+, C24.2, D1.-, D2.-, R4.2, T_EXT.T, U1.2 (VIN)
VRTC: C6.2, J1.+ (V+), U2.26 (VRTC)

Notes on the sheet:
close to connector
debug
soft start
voltage detect threshold 7V
connector
6mil

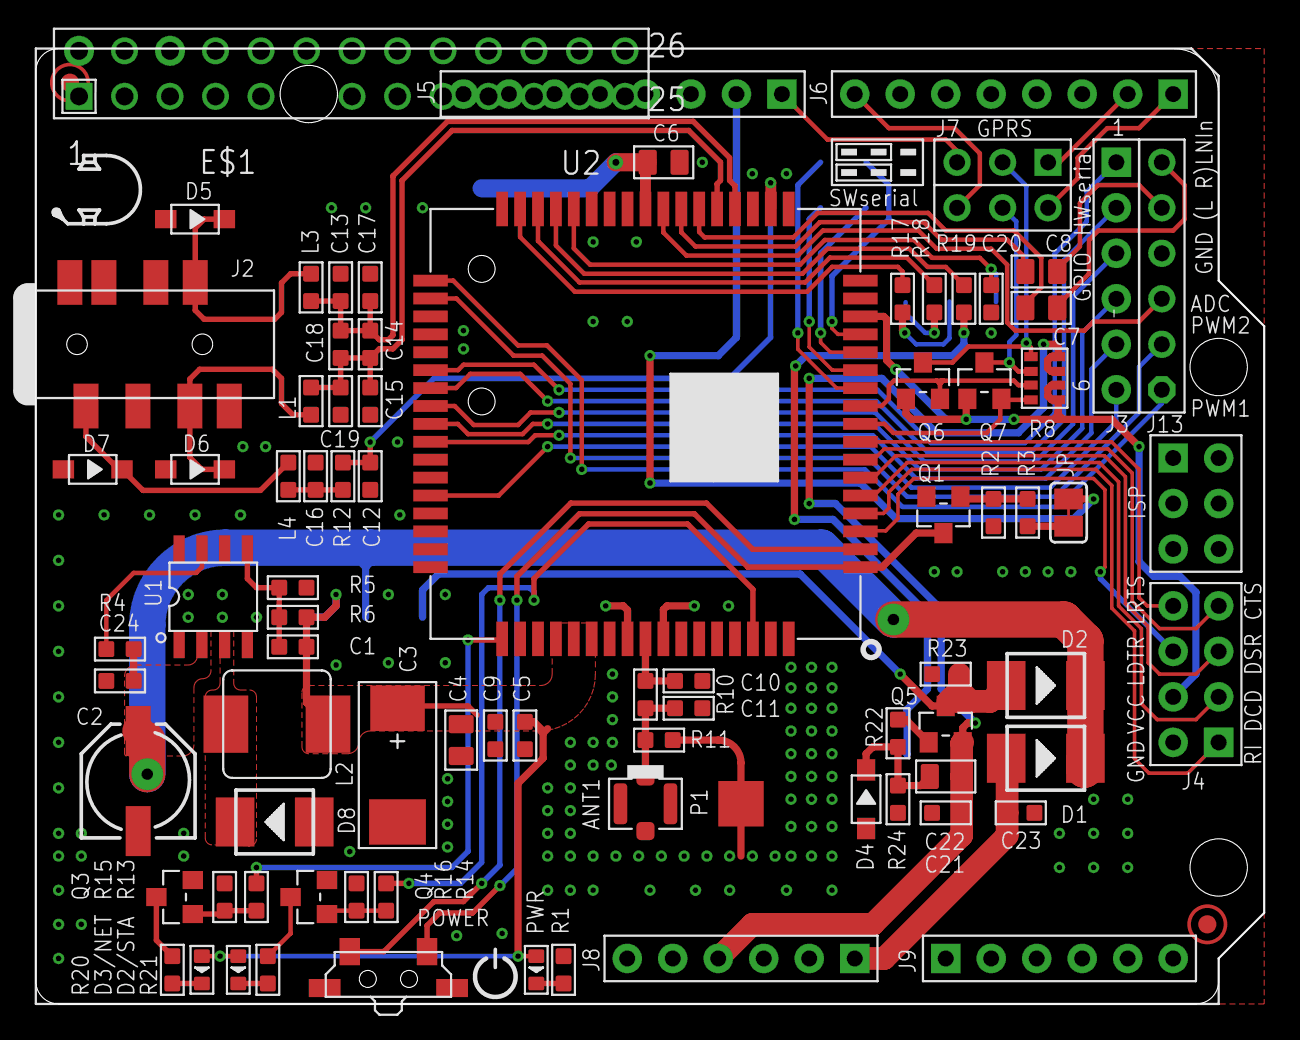
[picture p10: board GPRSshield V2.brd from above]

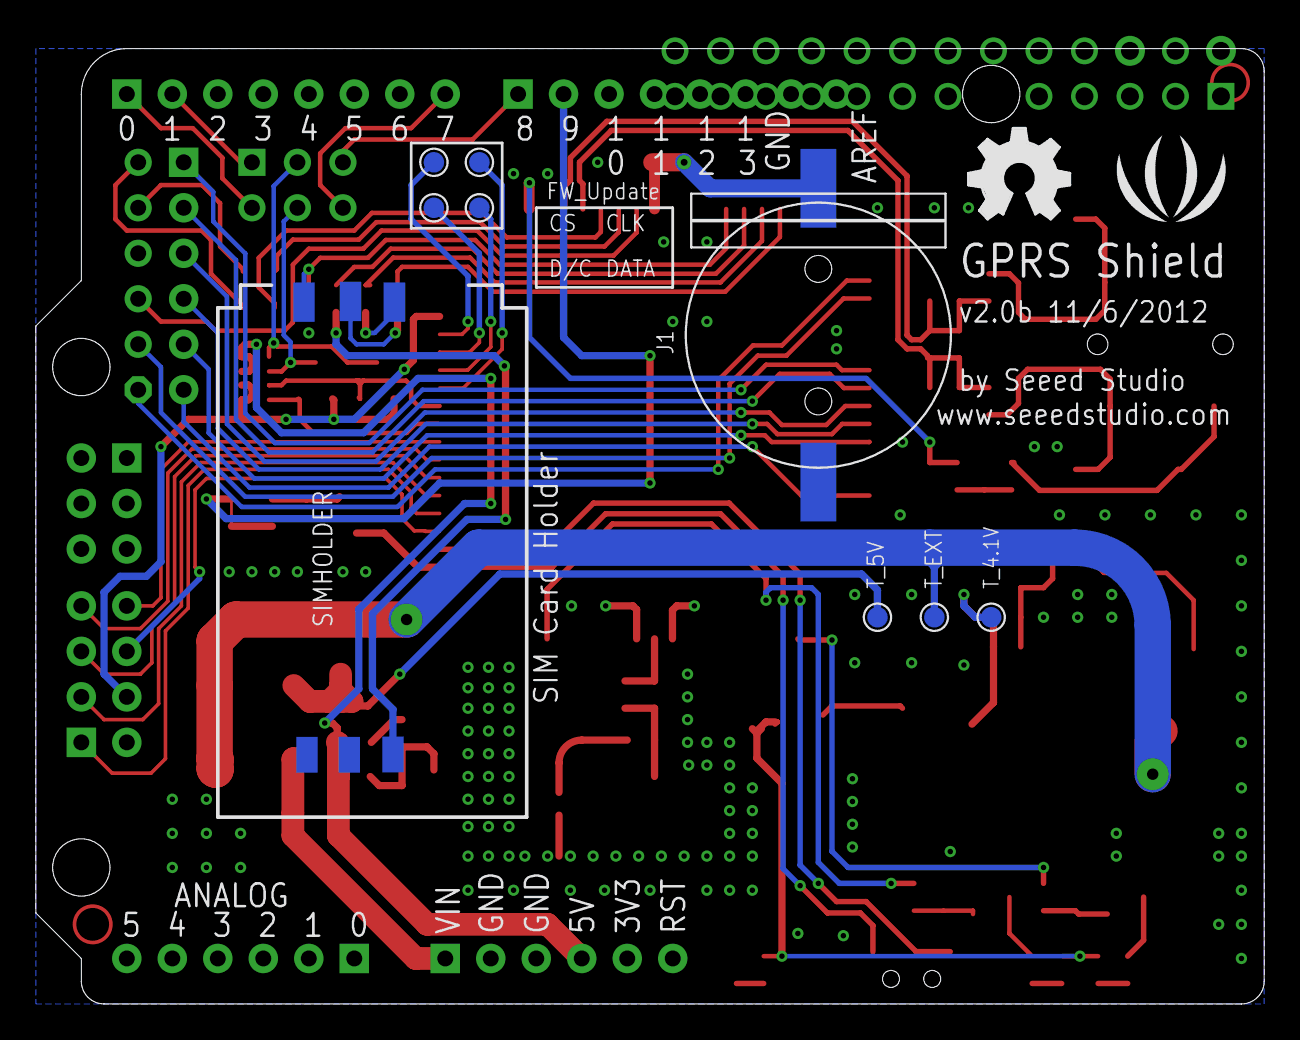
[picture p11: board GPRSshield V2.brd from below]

Board: 2 copper layers, 68.6 x 53.3 mm, 92 parts (11 on the bottom side), 74 nets.

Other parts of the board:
E$1: RASPBERRY-PI
U$26: LOGO_SILK
U$28: OSHW_FILLX200_NOTEXT

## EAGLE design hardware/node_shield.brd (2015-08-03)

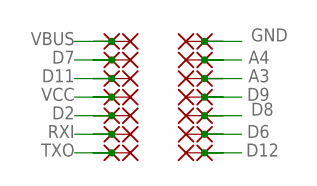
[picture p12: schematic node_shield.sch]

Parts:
PAD1, PAD2, PAD3, PAD4, PAD5, PAD6, PAD7, PAD8, PAD9, PAD10, PAD11, PAD12, PAD13, PAD14, PAD15, PAD16, PAD17, PAD18, PAD19, PAD20, PAD21, PAD22, PAD23, PAD24, PAD25, PAD26, PAD27, PAD28: SMD2; SMD1,27-2,54

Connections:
A3: PAD6.1, PAD24.1
A4: PAD5.1, PAD23.1
D2: PAD12.1, PAD19.1
D6: PAD4.1, PAD27.1
D7: PAD2.1, PAD16.1
D8: PAD11.1, PAD26.1
D9: PAD1.1, PAD25.1
D11: PAD7.1, PAD17.1
D12: PAD3.1, PAD28.1
GND: PAD8.1, PAD22.1
RXI: PAD14.1, PAD20.1
TXO: PAD13.1, PAD21.1
VBUS: PAD9.1, PAD15.1
VCC: PAD10.1, PAD18.1

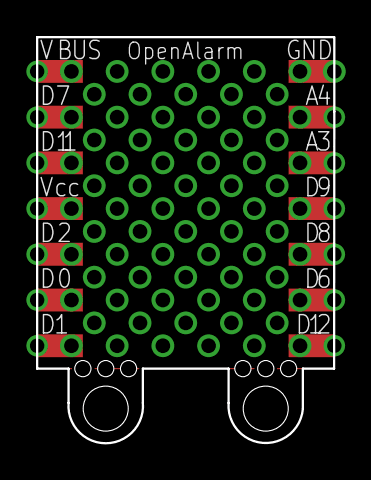
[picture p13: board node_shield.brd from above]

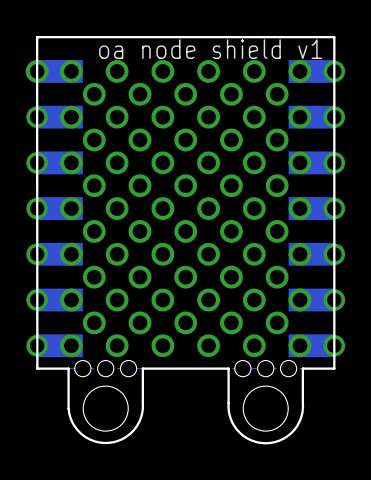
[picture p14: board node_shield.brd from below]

Board: 2 copper layers, 16.5 x 22.6 mm, 28 parts (14 on the bottom side), 14 nets.

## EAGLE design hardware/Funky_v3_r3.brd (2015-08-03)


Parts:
BAT2: BATTERY20PTH; BATTCOM_20MM_PTH
C2: 100nF; C0603K
C3: 1µ; 0603-CAP
C4: 10µ; 0805
C5: 1uF; C0603K
C6: 1u; C0603K
C7: 100nF; 0402-CAP
C8, C9: 22pF; 0402-CAP
C10: 1uF; 0402-CAP
D1: Green; LED-0603
D2: DIODESOD-323F; SOD-323F
IC2: LTC3525; SC70
JP1, JP2: M01PTH; 1X01
JP3: USB-MICROB
L1: 10 µH; 1210
PAD1, PAD2, PAD3, PAD4, PAD5, PAD6, PAD7, PAD8, PAD9, PAD10, PAD11, PAD12, PAD13, PAD14: SMD2; SMD1,27-2,54
Q1: P-MOSFET; SOT23
R1, R4: 22; 0402-RES
R2: 100K; R0402
R3: 10K; 0402-RES
R6: 330; 0402-RES
RFM12B1: RFM12B_MINPADS; RFM12B-MINPADS
S2: !RESET; TACTILE_SWITCH_SMD
TOREX-XC6206: MCP1703CB; SOT23
U3: ATMEGA32U4; QFN-44-NOPAD
U$2: AVR-ISP-6-EDGE; 6PAD_ISP
Y1: 8MHz; CRYSTAL-SMD-5X3

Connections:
A0: U3.36 (PF7(ADC7))
A1: U3.37 (PF6(ADC6))
A2: U3.38 (PF5(ADC5))
A3: PAD6.1, U3.39 (PF4(ADC4))
A4: PAD5.1, U3.40 (PF1(ADC1))
A5: U3.41 (PF0(ADC0))
AREF: C7.2, U3.42 (AREF)
D2: PAD12.1, U3.19 (PD1(SDA))
D3: RFM12B1.IRQ, U3.18 (PD0(SCL))
D4: D2.A, Q1.1 (G), U3.25 (PD4(ADC8))
D5: U3.31 (PC6)
D6: PAD4.1, U3.27 (PD7(ADC10))
D7: PAD2.1, U3.1 (PE6)
D8: PAD11.1, U3.28 (PB4(ADC11))
D9: PAD1.1, U3.29 (PB5(ADC12))
D10: R2.1, RFM12B1.SEL, U3.30 (PB6(ADC13))
D11: PAD7.1, U3.12 (PB7)
D12: PAD3.1, U3.26 (PD6(ADC9))
D13: R6.1, U3.32 (PC7)
D+: JP3.D+, R1.2
D-: JP3.D-, R4.2
GND: BAT2.2 (-), C2.2, C3.2, C4.2, C5.2, C6.2, C7.1, C8.2, C9.2, C10.1, D1.C, IC2.2 (GND1), IC2.5 (GND2), JP3.GND, JP3.MT1 (GND), JP3.MT2 (GND), PAD9.1, RFM12B1.GND, S2.1, TOREX-XC6206.1 (GND), U3.5 (UGND), U3.15 (GND), U3.23 (GND), U3.33 (PE2/!HWB), U3.35 (GND), U3.43 (GND), U$2.GND
MISO: RFM12B1.SDO (SDO/MISO), U3.11 (PB3(MISO)), U$2.MISO
MOSI: RFM12B1.SDI (SDI/MOSI), U3.10 (PB2(MOSI)), U$2.MOSI
unnamed: C9.1, U3.16 (XTAL2), Y1.1
unnamed: R1.1, U3.4 (D+)
unnamed: JP2.1, RFM12B1.ANT
unnamed: C8.1, U3.17 (XTAL1), Y1.3 (2)
unnamed: C10.2, U3.6 (UCAP)
unnamed: D1.A, R6.2
unnamed: R4.1, U3.3 (D-)
unnamed: Q1.3 (D), RFM12B1.VDD
unnamed: IC2.6 (SW), L1.2
RESET: D2.C, R3.1, S2.3 (2), U3.13 (!RESET), U$2.RST
RXI: PAD14.1, U3.20 (PD2(RX))
RXLED: U3.8 (PB0(SS))
SCK: RFM12B1.SCK, U3.9 (PB1(SCK)), U$2.SCK
TXLED: U3.22 (PD5)
TXO: PAD13.1, U3.21 (PD3(TX))
VBUS: C5.1, JP3.VBUS, PAD8.1, TOREX-XC6206.3 (VI), U3.2 (UVCC), U3.7 (VBUS), U$2.VCC
VCC: BAT2.1 (+), C2.1, C4.1, C6.1, IC2.4 (VOUT), PAD10.1, Q1.2 (S), R2.2, R3.2, TOREX-XC6206.2 (VO), U3.14 (VCC), U3.24 (AVCC), U3.34 (VCC), U3.44 (AVCC)
VIN: C3.1, IC2.1 (SHDN), IC2.3 (VIN), JP1.1, L1.1



Board: 2 copper layers, 21.8 x 22.6 mm, 43 parts (12 on the bottom side), 35 nets.

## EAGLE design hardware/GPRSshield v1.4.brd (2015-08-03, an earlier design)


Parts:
ANT1: ANTENNA-SMA-IPX; SMA-TO-IPX
AT1: U-FL; 4P-U-FL
C1, C2: 10u; 0603
C3, C4: 470u; AVX_D
C5, C20: 100n; 0603
C6: 4.7u; 0805
C7, C8: 2.2u; 0603
C9: 1uF; 0603
C10, C11: DNP; 0402
C12, C16: 33p; 0603
C13, C14, C15: 10p; 0402
C17, C18, C19: 33p; 0402
D1: MMSZ4689-V; SOD123-2.7X1.6
D2: red; LED-0603
D3: green; LED-0603
EXT_PWR: DC-044; DC-404
J1: HEADER-2X5P-2.54; 2X5P-2.54
J2, J5: 6p male dowm; CK_1X6
J3, J6: 6p female up; CK_1X6
J4: CK_2X6
J7: CK_2X3_DD; CK_2X3
J8, J12: 8p male dowm; CK_1X8
J9, J11: 8p female up; CK_1X8
J10: HEADER-4P'2.54-90D-FEMALE'; 4P-2.54-90D-FEMALE
J13: HEADER_1X6; CK_1X6
J14: HOLDER-BATTERY-2P-CR1220; CR1220
JP: PAD-SOLDERJUMPERNC; 2P-SMD-3.3X2
K1: BOTTON_1_DP; BTN_5.0_RST
MIC: AUDIO-SMT; 3.5-SMD
P1: JP
P2: PAD-JUMPER-2P; 2P-SMD-1.78X1.27
PWR: green; D0603
Q1, Q3, Q4: 9013; SOT23
Q2: Si5902BDC; 1206-8
R1: 1k; 0603
R2, R15, R16: 47k; 0603
R3, R13, R14: 4.7k; 0603
R4: 100k; 0603
R5: 470R; 0603
R6: 43K; 0603
R7: 510R; 0603
R8: 10k; 1206-8-3.3X2.4
R9: DNP; 0603
R10: 0R; 0402
R11: DNP; 0402
R12: 68R; 0603
R17, R18, R19: 22R; 0603
R20, R21: 300R; 0603
SIMHOLDER: SIMHOLDER3
SPK: AUDIO-SMT; 3.5-SMD
U1: MIC29302'BU'; TO-263
U2: SIM900
VBAT: DNP; CK_1*2
VIN: SWITCH-2CH-6P; 6P-2CH-2.54-7.6X3.0

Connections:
ADC: J13.3, U2.25 (ADC)
CTS: J1.4, U2.7 (CTS)
D9: J11.7, J12.2, JP.1
DCD: J1.2, U2.5 (DCD)
DISP_CLK: J10.1, U2.11 (DISP_CLK)
DISP_CS: J10.4, U2.14 (DISP_CS)
DISP_D/C: J10.3, U2.13 (DISP_D/C)
DISP_DATA: J10.2, U2.12 (DISP_DATA)
DSR: J1.3, U2.6 (DSR)
GND: AT1.GND1, AT1.GND2, AT1.GND3, C1.1, C2.1, C3.-, C4.-, C5.1, C6.1, C9.1, C10.1, C11.1, C12.2, C13.2, C15.1, C16.1, C17.2, C19.1, C20.2, D1.1, EXT_PWR.-, J1.10, J5.4, J5.5, J6.2, J6.3, J11.2, J12.7, J13.4, J14.-, MIC.COM1, MIC.COM2, P1.2, P2.2, Q1.2 (E), Q3.2 (E), Q4.2 (E), R1.2, R2.2, R5.1, R6.1, R9.1, R15.2, R16.2, SIMHOLDER.6 (GND), SPK.COM1, SPK.COM2, U1.3 (GND), U1.TAB (TAB_GND), U2.17 (GND), U2.18 (GND), U2.20 (MIC_N), U2.29 (GND), U2.39 (GND), U2.45 (GND), U2.46 (GND), U2.53 (GND), U2.54 (GND), U2.58 (GND), U2.59 (GND), U2.61 (GND), U2.62 (GND), U2.63 (GND), U2.64 (GND), U2.65 (GND), VBAT.2
GPIO1: J4.1, U2.40 (GPIO1/KBR4)
GPIO2: J4.12, U2.41 (GPIO2/KBR3)
GPIO3: J4.2, U2.42 (GPIO3/KBR2)
GPIO4: J4.11, U2.43 (GPIO4/KBR1)
GPIO5: J4.3, U2.44 (GPIO5/KBR0)
GPIO6: J4.10, U2.47 (GPIO6/KBC4)
GPIO7: J4.4, U2.48 (GPIO7/KBC3)
GPIO8: J4.9, U2.49 (GPIO8/KBC2)
GPIO9: J4.5, U2.50 (GPIO9/KBC1)
GPIO10: J4.8, U2.51 (GPIO10/KBC0)
GPIO11: J4.6, U2.67 (GPIO11)
GPIO12: J4.7, U2.68 (GPIO12)
HRXD: J7.2, Q2.7 (D), Q2.8 (D), R8.1
HTXD: J7.5, Q2.5 (D), Q2.6 (D), R8.2 (1)
LDBG_RX: U2.28 (DBG_RXD)
LDBG_TX: U2.27 (DBG_TXD)
LDTR: J1.6, U2.3 (DTR)
LINEIN_L: C8.2, U2.24 (LINEIN_L)
LINEIN_R: C7.2, U2.23 (LINEIN_R)
LRTS: J1.5, U2.8 (RTS)
LRXD: J1.7, Q2.1 (S), R8.3 (1), U2.10 (RXD)
LTXD: J1.8, Q2.3 (S), R8.4 (1), U2.9 (TXD)
MRXD: J7.1, J8.7, J9.2
MTXD: J7.6, J8.8, J9.1
unnamed: C10.2, R10.2, U2.60 (RF_ANT)
unnamed: R4.1, R6.2, U1.5 (ADJ)
unnamed: Q3.3 (C), R20.2
unnamed: R19.2, SIMHOLDER.4 (I/O)
unnamed: R18.1, SIMHOLDER.3 (CLK)
unnamed: R17.1, SIMHOLDER.2 (RST)
unnamed: D3.-, R20.1
unnamed: Q3.1 (B), R13.2, R15.1
unnamed: C9.2, D1.2, R7.1, R8.7 (2), R8.8 (2), R9.2
unnamed: R13.1, U2.52 (NETLIGHT)
unnamed: K1.P$1 (1), U2.2 (PWRKEY_OUT)
unnamed: ANT1.1, ANT1.2, ANT1.3, ANT1.4, P2.1
unnamed: C12.1, R12.1, U2.19 (MIC_P)
unnamed: JP.2, R3.1
unnamed: C13.1, C14.2, C17.1, C18.2, SPK.L, U2.21 (SPK_P)
unnamed: Q4.3 (C), R21.2
unnamed: D2.-, R21.1
unnamed: Q4.1 (B), R14.2, R16.1
unnamed: C14.1, C15.2, C18.1, C19.2, SPK.R, U2.22 (SPK_N)
unnamed: R14.1, U2.66 (STATUS)
unnamed: AT1.D, C11.2, R10.1, R11.2
unnamed: P1.1, R11.1
unnamed: C7.1, J13.6
unnamed: J8.6, J9.3
unnamed: J8.5, J9.4
unnamed: J8.4, J9.5
unnamed: J8.3, J9.6
unnamed: J8.2, J9.7
unnamed: C8.1, J13.5
unnamed: C16.2, MIC.L, MIC.R, R12.2
unnamed: J11.6, J12.3
unnamed: J11.5, J12.4
unnamed: J11.4, J12.5
unnamed: J11.3, J12.6
unnamed: Q1.1 (B), R2.1, R3.2
unnamed: J11.1, J12.8
unnamed: J2.4, J3.3
unnamed: J2.3, J3.4
unnamed: J2.2, J3.5
unnamed: J2.1, J3.6
unnamed: J5.6, J6.1
unnamed: J5.2, J6.5
unnamed: J5.1, J6.6
unnamed: PWR.-, R1.1
PWM1: J13.1, U2.35 (PWM1)
PWM2: J13.2, U2.36 (PWM2)
PWRKEY: K1.P$2 (2), Q1.3 (C), U2.1 (PWRKEY)
RI: J1.1, U2.4 (RI)
SCL: J2.6, J3.1, U2.38 (SCL)
SDA: J2.5, J3.2, U2.37 (SDA)
SIM_CLK: R18.2, U2.32 (SIM_CLK)
SIM_DATA: R19.1, U2.31 (SIM_DATA)
SIM_RST: R17.2, U2.33 (SIM_RST)
SIM_VDD: C20.1, SIMHOLDER.1 (VCC), U2.30 (SIM_VDD)
SRXD: J7.3, J11.8, J12.1
STXD: J7.4, J8.1, J9.8
VBAT: C4.+, C5.2, R4.2, R5.2, U1.4 (OUT), U2.55 (VBAT), U2.56 (VBAT), U2.57 (VBAT), VBAT.1
VBOARD: J5.3, J6.4, VIN.CH1A, VIN.CH2A
VDD_EXT: J1.9, Q2.2 (G), Q2.4 (G), R8.5 (2), R8.6 (2), U2.15 (VDD_EXT)
VEXT: EXT_PWR.+, VIN.CH1B, VIN.CH2B
VIN: C1.2, C2.2, C3.+, D2.+, D3.+, PWR.+, R7.2, U1.1 (EN), U1.2 (IN), VIN.COM1, VIN.COM2
VRTC: C6.2, J14.+, U2.26 (VRTC)

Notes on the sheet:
close to connector
debug
TITLE: GPRS Shield
SeeedStudio
Design:
Check:
Data: 2012/06/24
Vision: 1.4
Sheet: 1/1
power supply
The power trace should be short and wide, recommended above 80mil
The ground layer (top and bottom) must be connected with many vias,
especially under the module's shield case.
Uart voltage level shift
R7=510R,0603 package,max power is 1/10.
R7 disappear power =(Vin-Vz)2/R7, less than 1/10, is OK
RTC battery
SIM card holder
GPRS moudle
connector
Change Note:



Board: 2 copper layers, 77.0 x 57.1 mm, 79 parts (6 on the bottom side), 94 nets.

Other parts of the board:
LOGO1: LOGO-SEEEDSTUDIO-SILK; LOGO_SILK
LOGO2: LOGO-OSHW-FILLX0200-NT; OSHW_FILLX200_NOTEXT

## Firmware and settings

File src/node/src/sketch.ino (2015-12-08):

#include <avr/power.h>
#include <avr/sleep.h>
//#include <avr/eeprom.h>
#include <util/atomic.h>

#include <SerialCommand.h>

#include "pins_arduino.h"

// REMOTE define is in openalarm.h
//#define TEST
//#define TEMPERATURE_CALIBRATION

#include <openalarm.h>
#define RF69_COMPAT 0 // define this to use the RF69 driver i.s.o. RF12

#include <JeeLib.h>

/*  Todo:
 *  - Faire une commande permettant de setter la conf (ex: set timeout 0, etc...)
 *  - Pareil qu'au dessus mais avec get (ex: get timeout, etc...)
 *  - Si on débranche l'usb, lancer l'autostart !
 *  - Après un changement de nodeid, il faut refaire un rfm_init()
 *  - Relais mode
 *  - Faire des define pour les listen, etc...
 */

extern bool debug;

uint8_t led_mapping[] = {
    GREEN_LED_PIN, RED_LED_PIN
};

extern uint8_t frame_preamble[FRAME_PREAMBLE_ITEM_COUNT];

//extern char input_to_int_mapping[10];
extern uint8_t int_to_input_mapping[EINT_COUNT];
extern uint8_t ios_mapping[INPUTS_COUNT];

extern SerialCommand sCmd;

extern config_t config, config_default;
extern bool usb;
extern bool verbose;

extern uint8_t current_mode;
extern uint8_t remote_node_id;
extern bool remote_active;

uint8_t remote_wait_error_cycle;

bool usb_removed = false;

Payload_Frame payloadf;

bool usbloop = true;

#ifdef TEST
bool listen_mode_raw = false;
#endif

#ifdef TEST
void cmd_blink();
void cmd_test();
void cmd_try();
#endif

void cmd_read();
void cmd_int();
void cmd_io();

command commands[] = {
    { "help",       cmd_help,       "" }, //This help !" },
    { "?",          cmd_help,       "" }, //This help !" },
    { "config",     cmd_config,     "" }, //View config !" },
    { "verbose",    cmd_verbose,    "" }, //Set verbose !" },
    { "debug",      cmd_debug,      "" }, //Set debug !" },
    { "send",       cmd_send,       "" }, //Send data from RF" },
    { "rfinit",     cmd_rfinit,     "" }, //Init RF module" },

    { "get",        cmd_get,        "" },
    { "set",        cmd_set,        "" },

//    { "eew",        cmd_eew,        "EEPROM write" },
//    { "eer",        cmd_eer,        "EEPROM read" },
//    { "sleep",      cmd_sleep,      "Sleep !" },

    { "guard",      cmd_guard,      "" }, //Start guard mode" },
    { "listen",     cmd_listen,     "" }, //Listen mode" },
#ifdef REMOTE
    { "remote",     cmd_remote,     "" }, //Start a remote shell" },
#endif

    { "exit",       cmd_exit,       "" }, //Exit current mode" },

    { "frame",      cmd_frame,      "" }, //Frame config" },
    { "int",        cmd_int,        "" }, //Interrupt config" },
    { "io",         cmd_io,         "" }, //Input / Output config" },

#ifdef TEST
    { "blink",      cmd_blink,      "" }, // Blink leds
    { "test",       cmd_test,       "" }, //Test !" },
    { "try",        cmd_try,        "" }, //Try" },
    { "read",       cmd_read,       "" },
    { "volt",       cmd_volt,       "" },
    { "adc",        cmd_adc,        "" },
    { "sim",        cmd_sim,        "" },
    { "can",        cmd_can,        "" },
#endif
#ifdef TEMPERATURE_CALIBRATION
    { "temp",       cmd_temp,       "" },
#endif
//    { "reboot",     cmd_reboot,     "Go to beginning of application space !" },
};

CMD_HELP(commands, cmd_help);

ISR(WDT_vect) { Sleepy::watchdogEvent(); } // interrupt handler for JeeLabs Sleepy power saving


void cmd_guard() {
    PFLN("Starting guard mode !");
    usbloop = false;
    GUARD_MODE_START();
}

void cmd_exit() {
    if (LISTEN_IS_ACTIVE()) {
        LISTEN_MODE_EXIT();
        PFLN("Exit listen mode !");
#ifdef TEST
        listen_mode_raw = false;
#endif
    } else {
        PRINT_FAIL("No active mode !");
    }
}

static void showNibble (byte nibble) {
    char c = '0' + (nibble & 0x0F);
    if (c > '9') {
        c += 7;
    }
    Serial.print(c);
}

static void showByte (byte value) {
    showNibble(value >> 4);
    showNibble(value);
}

void cmd_listen() {
#ifdef TEST
    char *arg = sCmd.next();
    listen_mode_raw = !strcmp(arg, "raw");
#endif
    rfm_init();
    PFLN("Enter listen mode !");
    LISTEN_MODE_START();
}

/*
void cmd_reboot() {
    //asm volatile("jmp 0x7E00");
    asm volatile("jmp 0x0000");
}
*/

void cmd_send() {
    char *arg = 0;

    power_spi_enable();

    arg = sCmd.next();
    PF("Send ");
    P(strlen(arg));
    PF(" byte(s)");

    GREEN_LED_ON()

    rf12_sleep(-1);
    PF(".");

    RF12_WAIT_SEND();

    PF(".");
    rf12_sendStart(0, arg, strlen(arg));
    rf12_sendWait(0);
    PF(".");
    rf12_sleep(0);

    GREEN_LED_OFF();

    power_spi_disable();

    PLN("Done !");
}

/*
void cmd_eew() {
    char *arg = 0;
    uint8_t address = 0;

    arg = sCmd.next();
    address = atoi(arg);
    PF("Write address ");
    P(address);

    arg = sCmd.next();
    PF(", with data : ");
    PLN(arg);

    eep.write(address, atoi(arg));
}

void cmd_eer() {
    char *arg = 0;
    uint8_t address = 0;

    arg = sCmd.next();
    address = atoi(arg);
    PF("Read address ");
    P(address);
    PF(" : ");

    PLN(eep.read(address));
}
*/


#ifdef REMOTE
void cmd_rhelp();

void cmd_rhelp_wrap() {
    cmd_rhelp();
}

SerialCommand rsCmd;
command rcommands[] = {
    { "help",       cmd_rhelp_wrap, "" }, //This help !" },
    { "?",          cmd_rhelp_wrap, "" }, //This help !" },
    { "led",        cmd_rled,       "" }, //Led toggle" },
    { "period",     cmd_rperiod,    "" }, //Set period" },
    { "power",      cmd_rpower,     "" }, //Set power" },
    { "feedback",   cmd_rfeedback,  "" }, //Set feedback" },
    { "timeout",    cmd_rtimeout,   "" }, //Set timeout" },
    { "profile",    cmd_rprofile,   "" }, //Set timeout" },
    { "exit",       cmd_rexit,      "" }, //Exit remote shell" }
};

CMD_HELP(rcommands, cmd_rhelp);

uint8_t remote_payload[3];
uint8_t remote_payload_size = 0;

//#define PAYLOAD_PUSH(data)  remote_payload[remote_payload_size++] = data;
inline void remote_payload_push(uint8_t data) {
    remote_payload[remote_payload_size++] = data;
}

void cmd_rexit() {
    remote_payload_push(REMOTE_CMD_EXIT);
}

void cmd_rled() {
    char *arg = rsCmd.next();
    if (!strcmp(arg, "set")) {
        remote_payload_push(REMOTE_CMD_LED_SET);

        arg = rsCmd.next();
        remote_payload_push(atoi(arg));

        arg = rsCmd.next();
        remote_payload_push(atoi(arg));
    } else if (!strcmp(arg, "toggle")) {
        remote_payload_push(REMOTE_CMD_LED_TOGGLE);

        arg = rsCmd.next();
        remote_payload_push(atoi(arg));
    }
}

void cmd_rperiod() {
    char *arg = rsCmd.next();
    remote_payload_push(REMOTE_CMD_PERIOD);
    remote_payload_push(atoi(arg));
}

void cmd_rtimeout() {
    char *arg = rsCmd.next();
    remote_payload_push(REMOTE_CMD_TIMEOUT);
    remote_payload_push(atoi(arg));
}

void cmd_rpower() {
    char *arg = rsCmd.next();
    remote_payload_push(REMOTE_CMD_POWER);
    remote_payload_push(atoi(arg));
}

void cmd_rfeedback() {
    char *arg = rsCmd.next();
    remote_payload_push(REMOTE_CMD_FEEDBACK);
    remote_payload_push(atoi(arg));
}

void cmd_rprofile() {
    char *arg = rsCmd.next();
    if (!strcmp(arg, "set")) {
        remote_payload_push(REMOTE_CMD_PROFILE_SET);
        remote_payload_push(atoi(arg));
    }
}

void cmd_runrecognized(const char *command) {
    PLN(command);
    PF("Command '");
    P(command);
    PFLN("' not found !");
}

/*  cmd_remote
 *  Gestion de la fonction remote depuis la base
 *  1. La base attend de recevoir des données depuis le remote
 *  2. À la réception d'une donnée, la base envoie un accusé de réception avec
 *     un champs de données de 3 contenant 3 fois REMOTE_CMD_INIT signalant
 *     la demande de remote, la base passe en REMOTE_STATUS_WAIT_READY
 *  3. La remote envoie alors READY
 */
void cmd_remote() {
    uint8_t remote_connection_status = REMOTE_STATUS_OFF;
    unsigned long start_time, last_time, last_cmd_time;
    char *arg, *key;
    uint8_t nodeid;
    uint8_t ack_data[REMOTE_CMD_INIT_SIZE];
    uint8_t maxretry = 3;

    memset(&remote_payload, 0, sizeof(remote_payload));
    remote_payload_size = 0;

    rfm_init();

    arg = sCmd.next();
    if (!arg) {
        PRINT_FAIL("You must provide a node id !");
        return;
    }

    nodeid = atoi(arg);

    key = sCmd.next();
    if (!key) {
        PRINT_FAIL("You must provide a key !");
        return;
    }

    if (strlen(key) != KEY_SIZE) {
        PRINT_FAIL("Invalid key size !");
        return;
    }

    REMOTE_MODE_START();

    if (debug) {
        PF("Remote with node ");
        PLN(nodeid);
    }

    PFLN("Connecting!");

    remote_connection_status = REMOTE_STATUS_CONNECTING;

    start_time = last_time = last_cmd_time = millis();

    while (REMOTE_IS_ACTIVE()) {

        if (remote_connection_status == REMOTE_STATUS_CONNECTED) {
            rsCmd.readSerial();

            if (last_cmd_time + (long)((long)config.cmd_timeout * 1000) < millis()) {
                remote_payload_push(REMOTE_CMD_EXIT);
            }
        }

        if ((remote_connection_status == REMOTE_STATUS_CONNECTING || remote_connection_status == REMOTE_STATUS_WAIT_READY)
            && last_time + 1000 < millis()) {
            PF(".");
            last_time = millis();

            if (start_time + 30000 < millis()) {
                DEBUGLN("[timeout!]");
                REMOTE_MODE_EXIT();
                break;
            }
        }

        // Command ready to send ?
        if (remote_connection_status == REMOTE_STATUS_CONNECTED && remote_payload_size) {

            last_cmd_time = millis();

            if (debug) {
                print_remote_command(remote_payload[0]);
            }

            RF12_WAIT_SEND();

            maxretry = 3;
            while (maxretry--) {
                rf12_sendStart(RF12_HDR_ACK | nodeid, &remote_payload, remote_payload_size);
                rf12_sendWait(0);

                // Wait for ACK
                if (waitForAck()) {
                    PRINT_SUCCESS("Success!");
                    break;
                }
            }

            remote_payload_size = 0;
            if (remote_payload[0] == REMOTE_CMD_EXIT) {
                goto remote_exit;
            }
        }

        // Received command ?
        if (rf12_recvDone()) {

            // Skip bad crc
            if (rf12_crc != 0) {
                continue;
            }

            // Only this nodeid !
            if (((uint8_t)rf12_hdr & 0x1F) != nodeid) {
                continue;
            }

            // Handle only if wants ack !
            if (not RF12_WANTS_ACK) {
                DEBUGLN("Don't want ACK !");
                goto remote_exit;
            }

            switch (remote_connection_status) {
                case REMOTE_STATUS_CONNECTED:
                    switch (rf12_data[0]) {
                        case REMOTE_CMD_EXIT:
                            rf12_sendStart(RF12_ACK_REPLY, 0, 0);
                            //PF("Received exit command !");
                            goto remote_exit;
                        default:
                            //PFLN("Invalid command received !");
                            goto remote_exit;
                    }
                    break;

                // First step: Send init command !
                case REMOTE_STATUS_CONNECTING:
                    // Send command init X
                    memset(&ack_data, REMOTE_CMD_INIT, REMOTE_CMD_INIT_SIZE);
                    rf12_sendStart(RF12_ACK_REPLY, &ack_data, REMOTE_CMD_INIT_SIZE);

                    if (debug) {
                        PFLN("[ok!]");
                        PF("Wait ready command.");
                    }

                    start_time = millis();

                    remote_connection_status = REMOTE_STATUS_WAIT_READY;
                    break;

                case REMOTE_STATUS_WAIT_READY:
                    switch (rf12_data[0]) {
                        case REMOTE_CMD_READY:

                            // Reply with ack !
                            rf12_sendStart(RF12_ACK_REPLY, 0, 0);

                            payload_challenge_t payloadc;
                            payloadc.command = REMOTE_CMD_READY;
                            payloadc = *(payload_challenge_t*)rf12_data;

                            // Delay mandatory !
                            delay(10);

                            if (debug) {
                                PFLN("[ok!]");
                                PF("Received ready cmd with challenge : ");
                                PrintBytes(payloadc.challenge, KEY_SIZE);
                                PLN();

                                PF("Calculate with key : ");
                                PLN(key);
                            }

                            // Calculate challenge !
                            //for (uint8_t i = 0; i < min(KEY_SIZE, rf12_len); i++) {
                            for (uint8_t i = 0; i < KEY_SIZE; i++) {
                                payloadc.challenge[i] = payloadc.challenge[i] ^ key[i];
                            }

                            if (debug) {
                                PF("Send challenge : ");
                                PrintBytes(payloadc.challenge, KEY_SIZE);
                                PF(" ");
                            }
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
void loop() {

    //register_backup = EIMSK;
    //EIMSK = 0;

    //ATOMIC_BLOCK(ATOMIC_FORCEON)

    if (PROFILE_CURRENT.feedback) {
        GREEN_LED_ON()
        delay(50);
        GREEN_LED_OFF()
    }

    total = frame_fill();

    frame_sent++;

    //sei();

    if (usb_inserted()) {
        if (usb_removed) {
            usb_wake();
            command_prompt(0);

            guard_init();
            powersave();
        }
    } else {
        usb_removed = true;
    }

    // Send data via RF
    rfwrite(&payloadf.frame, total);

    /*  If you are here because of an external interrupt,
     *  detach all external interrupt for a while
     */
    if (PROFILE_CURRENT.eint_wait_cycle) {
        if (wake_type == WAKE_TYPE_EINT) {
            detachInterrupt(wake_arg);
            eint_wait_cycle[wake_arg] = PROFILE_CURRENT.eint_wait_cycle;
        } else {
            for (uint8_t c = 0; c < sizeof eint_wait_cycle; c++) {
                --eint_wait_cycle[c];

                // Todo: Optimize this code !
                if (eint_wait_cycle[c] <= 0) {
                    for (uint8_t i = 0; i < PROFILE_CURRENT.interrupts_count; i++) {
                        if (INT_NUM_FROM_FIELD_BITS(PROFILE_CURRENT.interrupts[i]) == c) {
                            attachInterrupt(INT_NUM_FROM_FIELD_BITS(PROFILE_CURRENT.interrupts[i]),
                                            int_functions[INT_NUM_FROM_FIELD_BITS(PROFILE_CURRENT.interrupts[i])],
                                            INT_TYPE_FROM_FIELD_BITS(PROFILE_CURRENT.interrupts[i]));
                            break;
                        }
                    }
                }
            }
        }
    }

    // Update error counter
    if (remote_wait_error_cycle) {
        remote_wait_error_cycle--;

        remote_active = (!remote_wait_error_cycle && config.remote & (1 << CONFIG_REMOTE_ACTIVE_BIT));
    }

    wake_type = WAKE_TYPE_TIMER;
    wake_arg = PROFILE_CURRENT.period;

    //EIMSK = register_backup;

#ifdef REMOTE
    if (REMOTE_IS_ACTIVE()) {
        remote_handler();
    }
#endif

    // Todo: Remove this : precalculate this value in guard_init !
    dodelay(PROFILE_CURRENT.period * 1000);
}

#ifdef TEST
void cmd_blink() {
    char *arg = sCmd.next();
    for (uint8_t i = 0; i < atoi(arg); i++) {
        GREEN_LED_ON();
        RED_LED_ON();
        delay(300);
        GREEN_LED_OFF();
        RED_LED_OFF();
        delay(300);
    }
}

void cmd_test() {
    char *arg = 0;

    arg = sCmd.next();
    if (!strcmp(arg, "usb")) {
        PFLN("Test usb insertion !");

        while (1) {
            P(".");
            delay(300);
            //if (BIT_TEST(USBSTA, VBUS)) {
            if (usb_inserted()) {
                RED_LED_ON();
                PLN("USB!");
            } else {
                RED_LED_OFF();
            }
        }
    } else if (!strcmp(arg, "io")) {

        PFLN("Test io !");

        uint8_t ios[] = { 0, 1, 2, 3, 4, GREEN_LED_PIN, 6, 7, 8, 9, 12, RED_LED_PIN };

        for (uint8_t i = 0; i < sizeof ios; i++) {
            pinMode(i, OUTPUT);
        }

        bool status = true;
        while (1) {
            PF("Set ios to ");
            PLN(status);

            for (uint8_t i = 0; i < sizeof ios; i++) {
                digitalWrite(ios[i], status);
            }

            delay(500);

            status = not status;
        }
    } else if (!strcmp(arg, "rfwrite")) {

        rfwrite(&payloadf.frame, 1);

    } else if (!strcmp(arg, "sleep")) {

        PFLN("Test sleep !");

        usb = false;

        GREEN_LED_OFF();
        RED_LED_ON();

        Serial.flush();

        powersave();

        while (1) {
            dodelay(3000);

            digitalWrite(RED_LED_PIN, not digitalRead(RED_LED_PIN));
        }
    } else {
        PLN("No arg !");
    }
}

volatile bool paf = false;
void tototo() {
    paf = not paf;
}

void cmd_try() {
    PLN("Try !");

    attachInterrupt(3, tototo, INTERRUPT_FALLING);

    bool last_paf = paf;
    while (1) {
        GREEN_LED_ON();
        delay(200);
        GREEN_LED_OFF();
        delay(200);

        if (paf != last_paf) {
            if (paf) {
                RED_LED_OFF();
            } else {
                RED_LED_ON();
            }

            delay(500);
        }

        last_paf = paf;
    }
}

void cmd_read() {
    int value = 0;
    char *arg = sCmd.next();
    uint8_t index = atoi(arg);

    switch (index) {
        case FC_TYPE:
        case FC_COUNTER:
        case FC_WAKETYPE:
        case FC_WAKEARG:
            break;
        case FC_INPUT0:
        case FC_INPUT1:
        case FC_INPUT2:
        case FC_INPUT3:
        case FC_INPUT4:
        case FC_INPUT5:
        case FC_INPUT6:
        case FC_INPUT7:
            if (!FRAME_ITEM_IS_BIT(index)) {
                PFLN("Arg not a bit !");
            }

            value = digitalRead(FRAME_INPUT_TO_PIN(index));
            break;
        case FC_ANALOG0:
        case FC_ANALOG1:
        case FC_ANALOG2:
        case FC_ANALOG3:
        case FC_ANALOG4:
        case FC_ANALOG5:
            value = analogRead(FRAME_ANALOG_TO_PIN(PROFILE_CURRENT.frame[total]));
            break;
        case FC_VOLTAGE:
            value = read_vcc();
            break;
        case FC_TEMPERATURE:
            //value = read_temperature();
            value = TEMPERATURE_GET_CALIBRATED();
            break;
    }

    P("Read ");
    P(index);
    P(" : ");
    PLN(value);
}
//uint8_t calibration = 0;

void cmd_adc() {
    int voltage;
    char *arg = sCmd.next();

    PF("adc was ");
    if ((PRR0 >> PRADC) & 1) {
        PLN("off");
    } else {
        PLN("on");
    }

    if (atoi(arg)) {
        PFLN("adc enable !");
        power_adc_enable();
    } else {
        PFLN("adc disable !");
        power_adc_disable();
    }
}

void cmd_sim() {
    char *arg = sCmd.next();

    if (atoi(arg)) {
        //ADCSRA = 0;
        power_adc_disable();
        ACSR |= (1 << ACD);
        PFLN("Sim on !");
    } else {
        //ADCSRA = 0;
        power_adc_enable();
        ACSR &= ~(1 << ACD);
        ACSR = 0;
        PFLN("Sim off !");
    }
}

void cmd_can() {
    char *arg = sCmd.next();

    PF("Analog comparator was ");
    if ((ACSR >> ACD) & 1) {
        PLN("off");
    } else {
        PLN("on");
    }

    PF("Analog comparator ");
    if (atoi(arg)) {
        PFLN("enable !");
        ACSR &= ~(1 << ACD);
    } else {
        PFLN("disable !");
        ACSR |= (1 << ACD);
    }
}

/*
#define TEMP_OFFSET 10
 
void setupADC(){
  cli();  //Disable global interrupts
 
  //ADC Multiplexer Selection Register
  ADMUX = 0;
  ADMUX |= (1 << REFS1);  //Internal 2.56V Voltage Reference with external capacitor on AREF pin
  ADMUX |= (1 << REFS0);  //Internal 2.56V Voltage Reference with external capacitor on AREF pin
  ADMUX |= (0 << MUX4);  //Temperature Sensor - 100111
  ADMUX |= (0 << MUX3);  //Temperature Sensor - 100111
  ADMUX |= (1 << MUX2);  //Temperature Sensor - 100111
  ADMUX |= (1 << MUX1);  //Temperature Sensor - 100111
  ADMUX |= (1 << MUX0);  //Temperature Sensor - 100111
 
  //ADC Control and Status Register A 
  ADCSRA = 0;
  ADCSRA |= (1 << ADEN);  //Enable the ADC
  ADCSRA |= (1 << ADPS2);  //ADC Prescaler - 16 (16MHz -> 1MHz)
 
  //ADC Control and Status Register B 
  ADCSRB = 0;
  ADCSRB |= (1 << MUX5);  //Temperature Sensor - 100111
 
  sei();  //Enable global interrupts
}
 
int getTemp(){
  ADCSRA |= (1 << ADSC);  //Start temperature conversion
  while (bit_is_set(ADCSRA, ADSC));  //Wait for conversion to finish
  byte low  = ADCL;
  byte high = ADCH;
  int temperature = (high << 8) | low;  //Result is in kelvin
  return temperature - 273 + TEMP_OFFSET;
}
        setupADC();
*/
 
void cmd_volt() {
    int temperature = 0;
    while (Serial.read() != '\r') {
        P("read voltage: ");
        PLN(read_voltage());
        delay(100);

        P("read temp: ");
        //PLN(read_temperature());
        temperature = TEMPERATURE_GET_CALIBRATED();
        //delay(2);
        //temperature = TEMPERATURE_GET_CALIBRATED();
        P((float)temperature);
        PFLN("˚C");
        delay(900);

        /*
        PF("getTemp:");
        P((float)getTemp());
        PFLN("˚C");
        delay(100);

        delay(1000);

        analogRead(6);
        bitSet(ADMUX, 3);
        //delay(250);
        delayMicroseconds(250);
        bitSet(ADCSRA, ADSC);
        while (bit_is_set(ADCSRA, ADSC));
        word x = ADC;
        //P("New: ");
        //PLN((1100L * 1023) / x);
        */
    }
}
#endif
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

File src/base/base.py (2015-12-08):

from __future__ import division
import sys
import time
import yaml as yamllib
from enum import Enum, unique
import serial
import contextlib
from docopt import docopt

# Todo: Si on essaie de programmer un node et que le node connecté ne correspond pas
# au nodeid, on demande confirmation !

DELAY = 0.01
FILE = 'oa.yaml'

with open(FILE) as f:
    yaml = yamllib.load(f)

class OAException(Exception):
    pass

IO_TO_EXT_INT = [ 2, 3, 1, 0, -1, -1, -1, 6, 4, 5 ]
EXT_INT_TYPE = ( 'falling', 'change', 'rising' )

IOS = ( 0, 1, 2, 3, -1, -1, 6, 7, 8, 9 )
IO_STATE = ( 'input', 'output', 'low', 'high', 'pullup', 'nopullup' )

frame_mandatory_fields = ('counter', 'waketype', 'wakearg')

@unique
class FRAME_CONTENT(Enum):
    # Preamble
    TYPE = 1
    COUNTER = 2
    WAKETYPE = 3
    WAKEARG = 4

    # Digital input
    INPUT0 = 8
    INPUT1 = 9
    INPUT2 = 10
    INPUT3 = 11
    INPUT4 = 12
    INPUT5 = 13
    INPUT6 = 14
    INPUT7 = 15
    INPUT8 = 16
    INPUT9 = 17

    # Analog input
    ANALOG0 = 32
    ANALOG1 = 33
    ANALOG2 = 34
    ANALOG3 = 35
    ANALOG4 = 36
    ANALOG5 = 37

    # Analog value
    VOLTAGE = 64
    TEMPERATURE = 65

f = FRAME_CONTENT
frame_content_map = {
    'type':         (f.TYPE, 1),
    'counter':      (f.COUNTER, 2),
    'waketype':     (f.WAKETYPE, 1),
    'wakearg':      (f.WAKEARG, 1),
    'input0':       (f.INPUT0, 1),
    'input1':       (f.INPUT1, 1),
    'input2':       (f.INPUT2, 1),
    'input3':       (f.INPUT3, 1),
    'input4':       (f.INPUT4, 1),
    'input5':       (f.INPUT5, 1),
    'input6':       (f.INPUT6, 1),
    'input7':       (f.INPUT7, 1),
    'input8':       (f.INPUT8, 1),
    'input9':       (f.INPUT9, 1),
    'analog0':      (f.ANALOG0, 2),
    'analog1':      (f.ANALOG1, 2),
    'analog2':      (f.ANALOG2, 2),
    'analog3':      (f.ANALOG3, 2),
    'analog4':      (f.ANALOG4, 2),
    'analog5':      (f.ANALOG5, 2),
    'voltage':      (f.VOLTAGE, 2),
    'temperature':  (f.TEMPERATURE, 1)
}

class Profile:
    name = ''
    description = ''
    ext_int = {}
    ios = {}
    frame = None

    feedback = True
    eintwait = 2
    period = 5

    def __init__(self):
        self.name = self.description = ''
        self.ext_int = {}
        self.ios = {}
        self.frame = {}

    def __repr__(self):
        return '%s' % (self.description)

class Config:
    __name = ''
    freq = ''
    group = ''
    ack = 0
    power = 0
    cmdtimeout = 0
    usbtimeout = 0
    autostart = ''
    remote = {}

    @staticmethod
    def format(name, value):
        if name == 'name':
            return str(value)
        elif name == 'group':
            return int(value)
        elif name == 'freq':
            if value in (433, 868, 915):
                return str(value)[0]
            return None
        elif name in ('ack', 'autostart'):
            return 0 if not int(value) else 1
        elif name == 'power':
            value = int(value)
            return value if 0 <= value <= 7 else None
        elif name in ('cmdtimeout', 'usbtimeout'):
            return int(value)
        elif name == 'remote':
            return "%i %i" % (int((value['active'] is True)), int(value['wait_error_cycle']))

class Frame:
    id = ''
    name = ''
    content = []

    def __init__(self):
        self.content = []

    def __repr__(self):
        return '%i:%s (%s)' % (self.id, self.name, self.content)

def parse_devices():
    devices = {}
    for name, content in yaml['devices'].items():
        devices[name] = content
    return devices

def parse_nodes():
    nodes = {}
    for name, content in yaml['nodes'].items():
        nodes[name] = content
    return nodes

def parse_config(content, name=None):
    config = Config()
    for name, content in content.items():
        if name:
            config.__name = name

        if name in vars(Config) and name[0:2] == '__':
            continue

        setattr(config, name, Config.format(name, content));
    return config

def parse_frame(content):
    # Frame
    try:
        def frame_add(s):
            key, _ = frame_content_map[s]
            frame.content.append(key)

        frame = Frame()
        frame.id = content['id']

        # Add mandatory fields
        for field in frame_mandatory_fields:
            if field not in frame.content:
                frame_add(field)

        try:
            frame.name = content['name']
        except KeyError:
            pass

        for item in content['content']:
            if item in frame_mandatory_fields:
                continue

            try:
                if type(item) == list:
                    for c in item:
                        frame_add(c)
                else:
                    frame_add(item)
            except KeyError:
                raise OAException("Unknow frame item: %s" % (item))
    except OAException as e:
        print(e)
        return

    return frame

def parse_frames():
    frames = {}
    for name, content in yaml['frames'].items():
        frames[name] = parse_frame(content)
    return frames

# Declare
if 'declare' in yaml:
    for index, item in yaml['declare'].items():
        if index in frame_content_map:
            raise OAException("Frame %s already exists !" % (index))
        frame_content_map[index] = tuple(item)
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

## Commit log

2014-01-17 Doc + Funky v3
    [Funky_v3_r3.brd, Funky_v3_r3.sch]
2015-06-10 Node version 1.0.0
    [node.GBL, node.GBO, node.GBP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]
2015-08-03 Hardware update
    Node 1.0.0, export and node shield
    [Funky_v3_r3.brd, Funky_v3_r3.sch, GPRSshield V2.brd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]
2015-08-09 Before resize
    [node.brd, node.sch]
2015-08-15 Node Shield
    [node_shield.GBL, node_shield.GBO, node_shield.GBP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]
2015-08-15 New node
    [node.brd, node.sch]
2015-08-21 Node
    Avancement
    [node.brd, node.sch]
2015-08-27 Max1555 backup
    Finally, design with max1555 is a bad idea !
    [node.brd, node.sch]
2015-08-28 Node + Proto Shield + Lipo Shield
    [node.brd, node.sch]
2015-08-28 Node + 2 Proto Shield + Lipo Shield
    [node.brd, node.sch]
2015-09-24 Node 1.5.0
    [node.GBL, node.GBO, node.GBP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]
2015-10-06 Hardware modification
    [node.brd, node.sch]
2015-12-08 Bug correction with remote command
    [base.py]

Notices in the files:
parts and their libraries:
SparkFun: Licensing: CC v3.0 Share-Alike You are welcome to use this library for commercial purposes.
